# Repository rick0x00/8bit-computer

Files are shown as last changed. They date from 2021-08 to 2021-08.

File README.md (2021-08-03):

# 8bit-computer

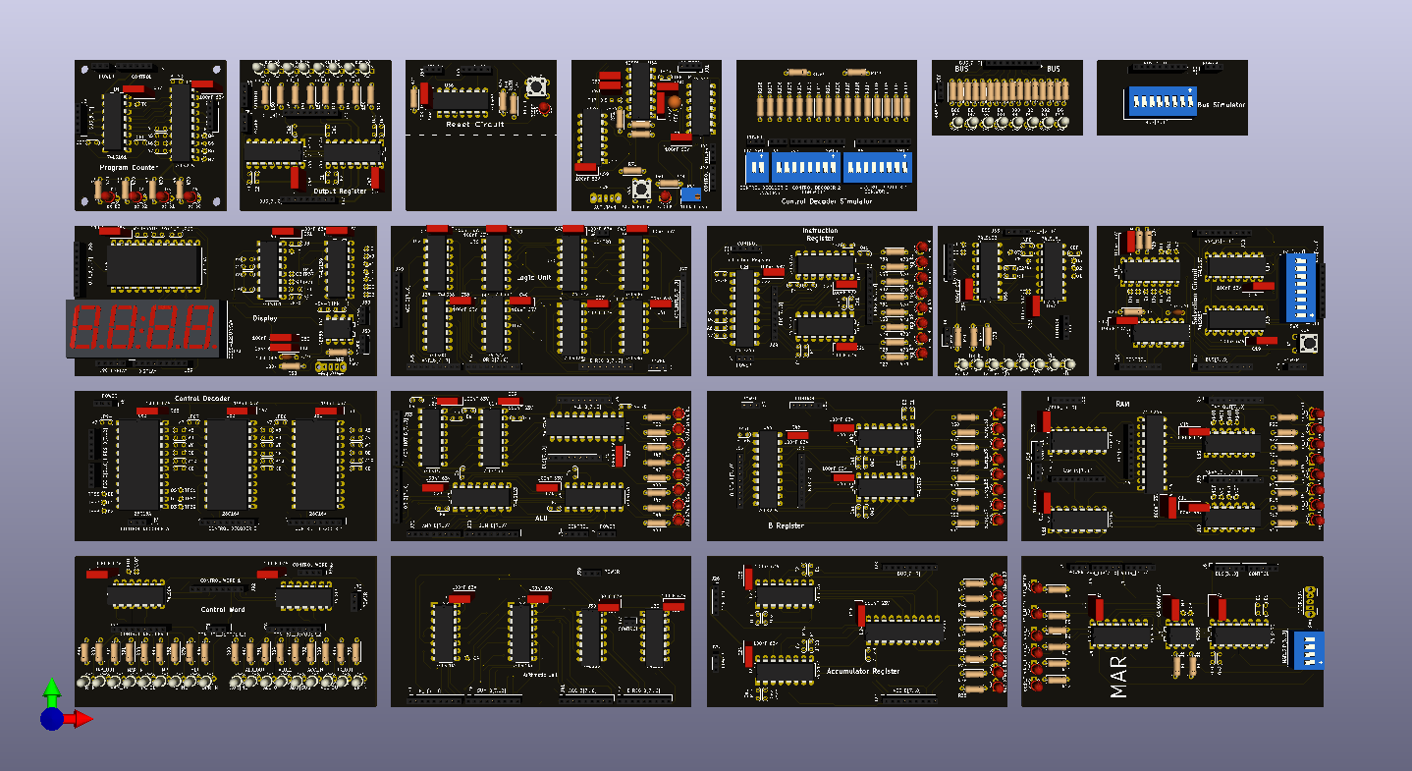
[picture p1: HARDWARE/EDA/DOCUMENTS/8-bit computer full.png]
8bit computer 3D image Kicad


This project intends to develop and distribute following the principles of the [Open Source Initiative(OSI)](https://opensource.org/osd).

The project was based on the model presented by [Wagner Rambo](https://youtube.com/playlist?list=PLZ8dBTV2_5HTB43Mhfz-TyIATkECrp8XY) and also by the project presented by [Ben Eater](https://youtube.com/playlist?list=PLowKtXNTBypGqImE405J2565dvjafglHU), both on youtube!

## Warning
I, the project maintainer ,am a beginner in this Open Source world, Git, GitHub... So I apologize in advance for any problems.

## License
At the present time this project is completely under [Apache 2.0 license](http://www.apache.org/licenses/LICENSE-2.0). All Softwares, All Electronic Designs(Schematics), All Documentation and All 3D Design.

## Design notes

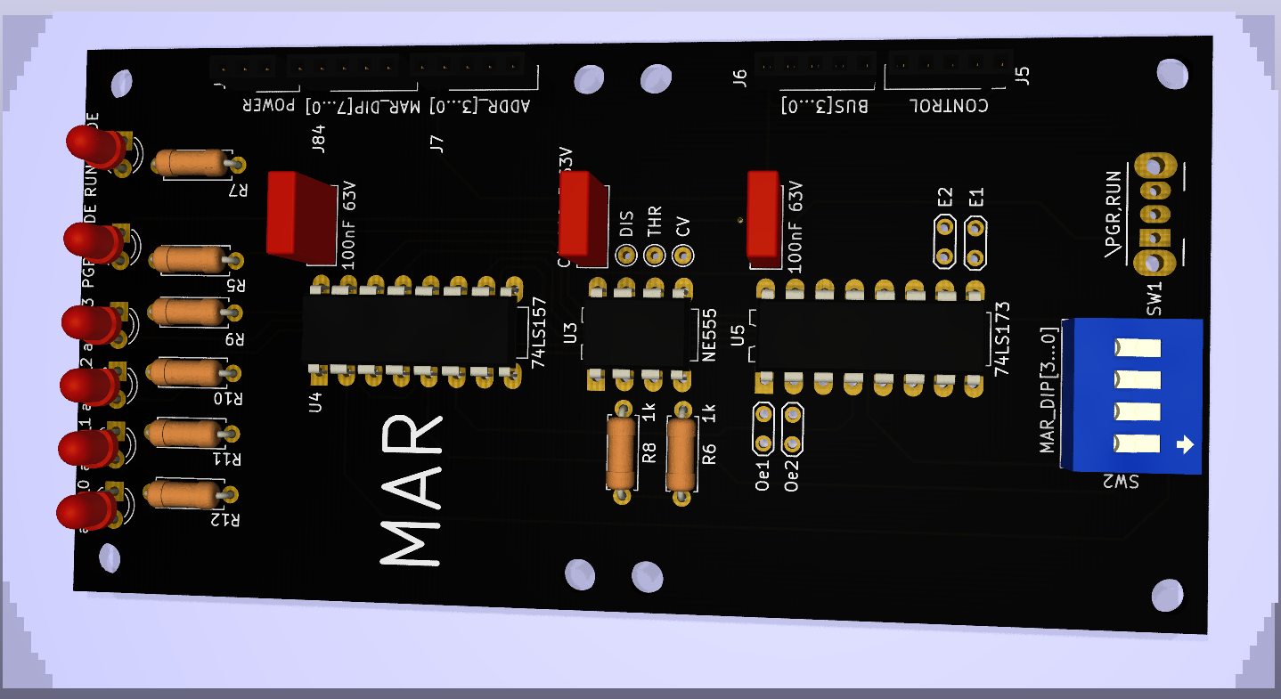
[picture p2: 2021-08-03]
HARDWARE/EDA/DOCUMENTS/MAR.png

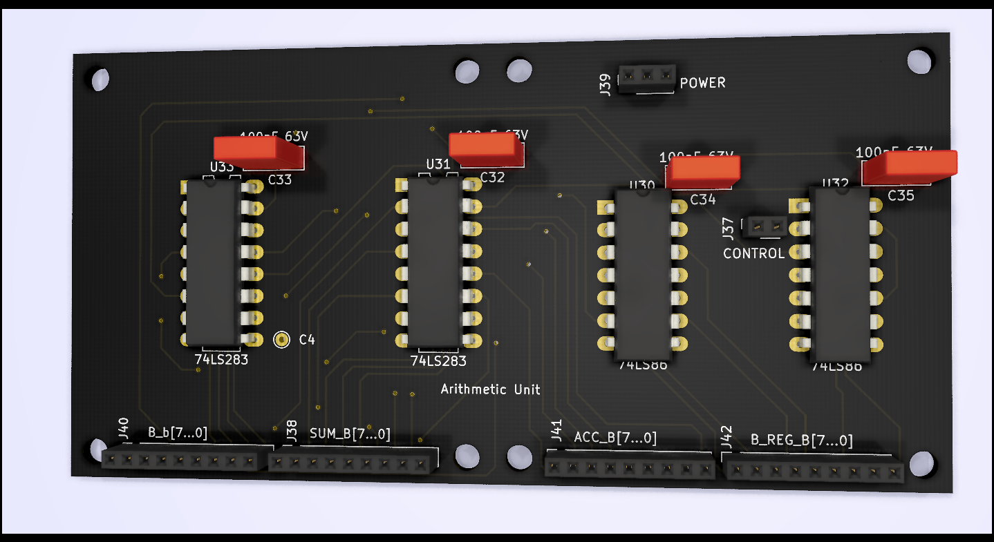
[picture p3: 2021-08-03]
HARDWARE/EDA/DOCUMENTS/Arithmetic Unit.png

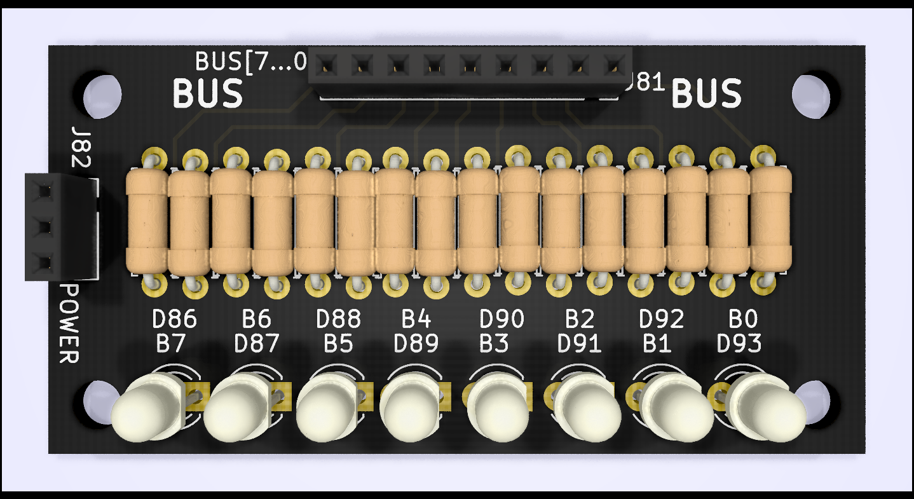
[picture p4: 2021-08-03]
HARDWARE/EDA/DOCUMENTS/BUS.png

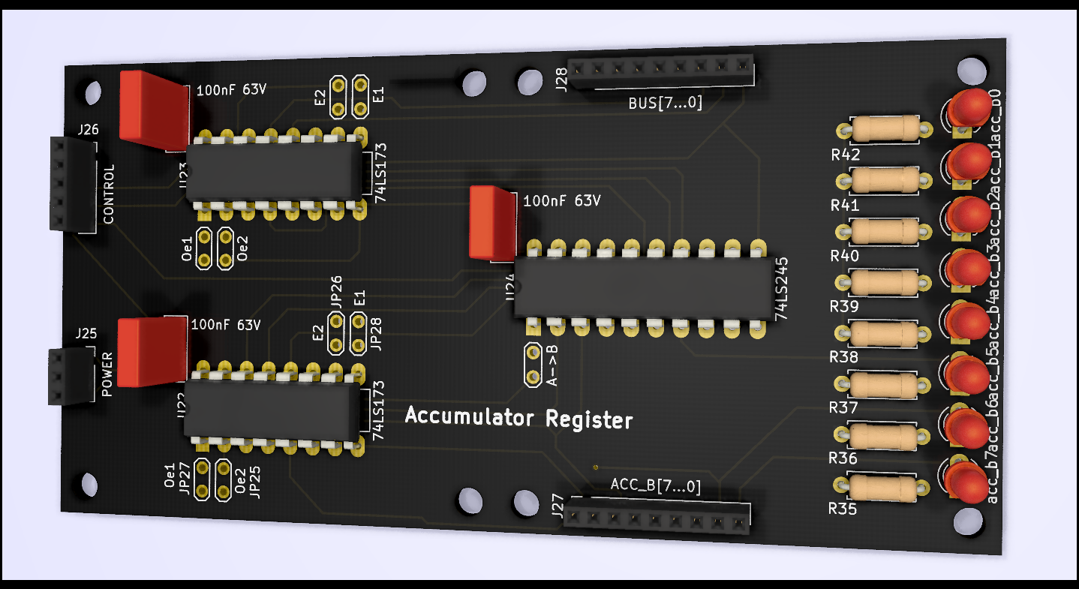
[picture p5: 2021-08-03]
HARDWARE/EDA/DOCUMENTS/Accumulator Register.png

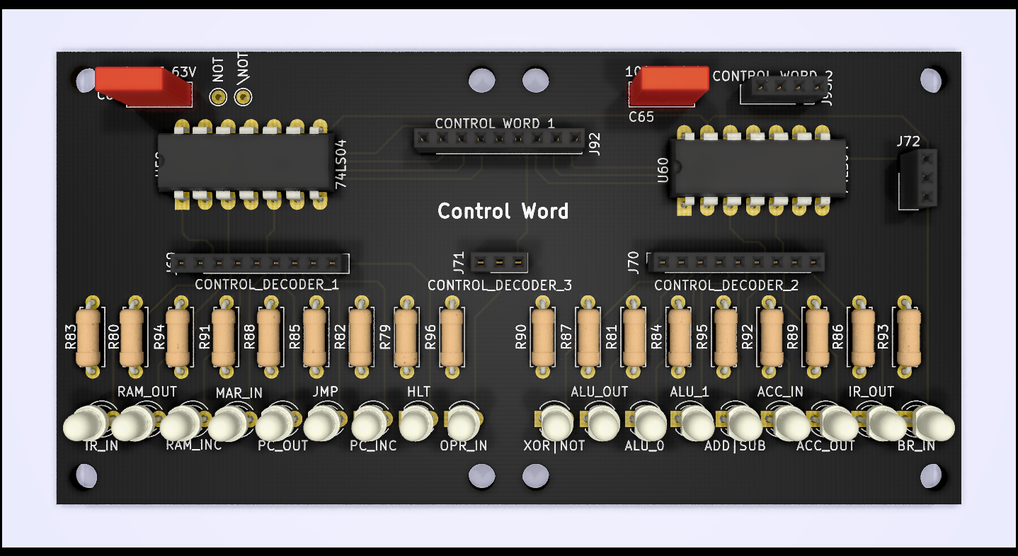
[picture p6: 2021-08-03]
HARDWARE/EDA/DOCUMENTS/Control Word.png

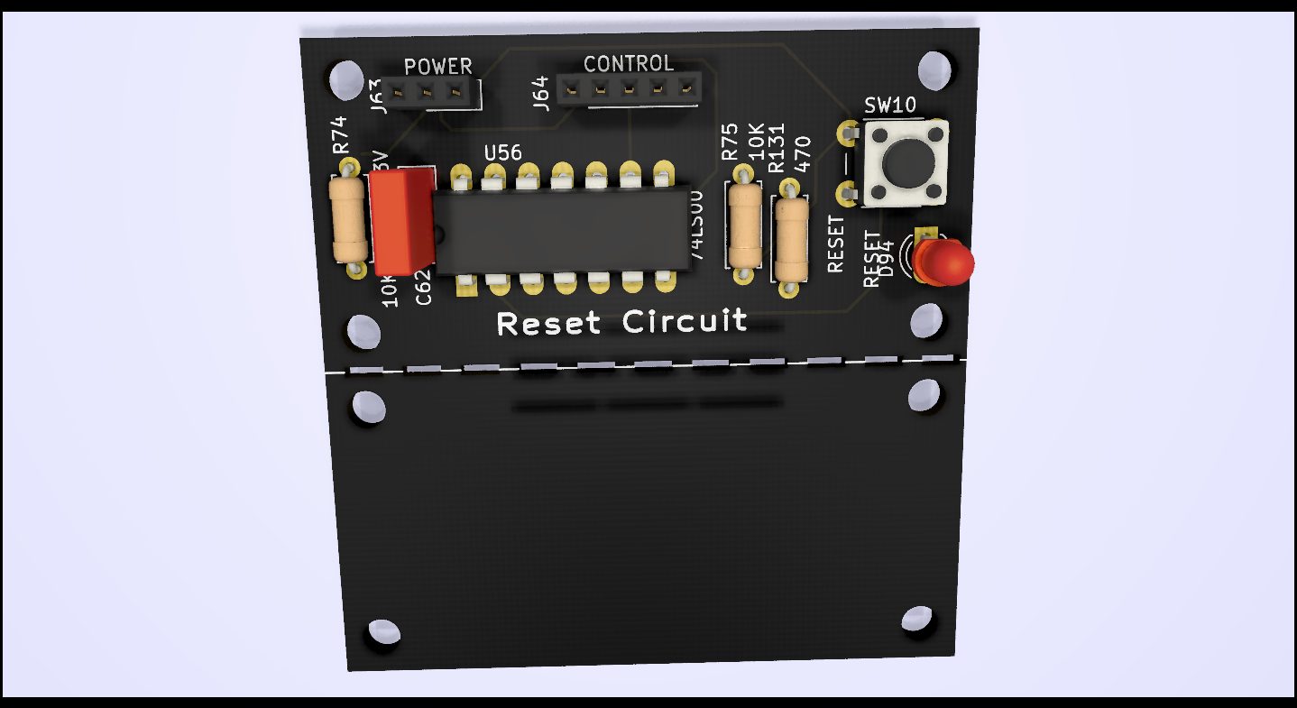
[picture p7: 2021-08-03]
HARDWARE/EDA/DOCUMENTS/Reset Circuit.png

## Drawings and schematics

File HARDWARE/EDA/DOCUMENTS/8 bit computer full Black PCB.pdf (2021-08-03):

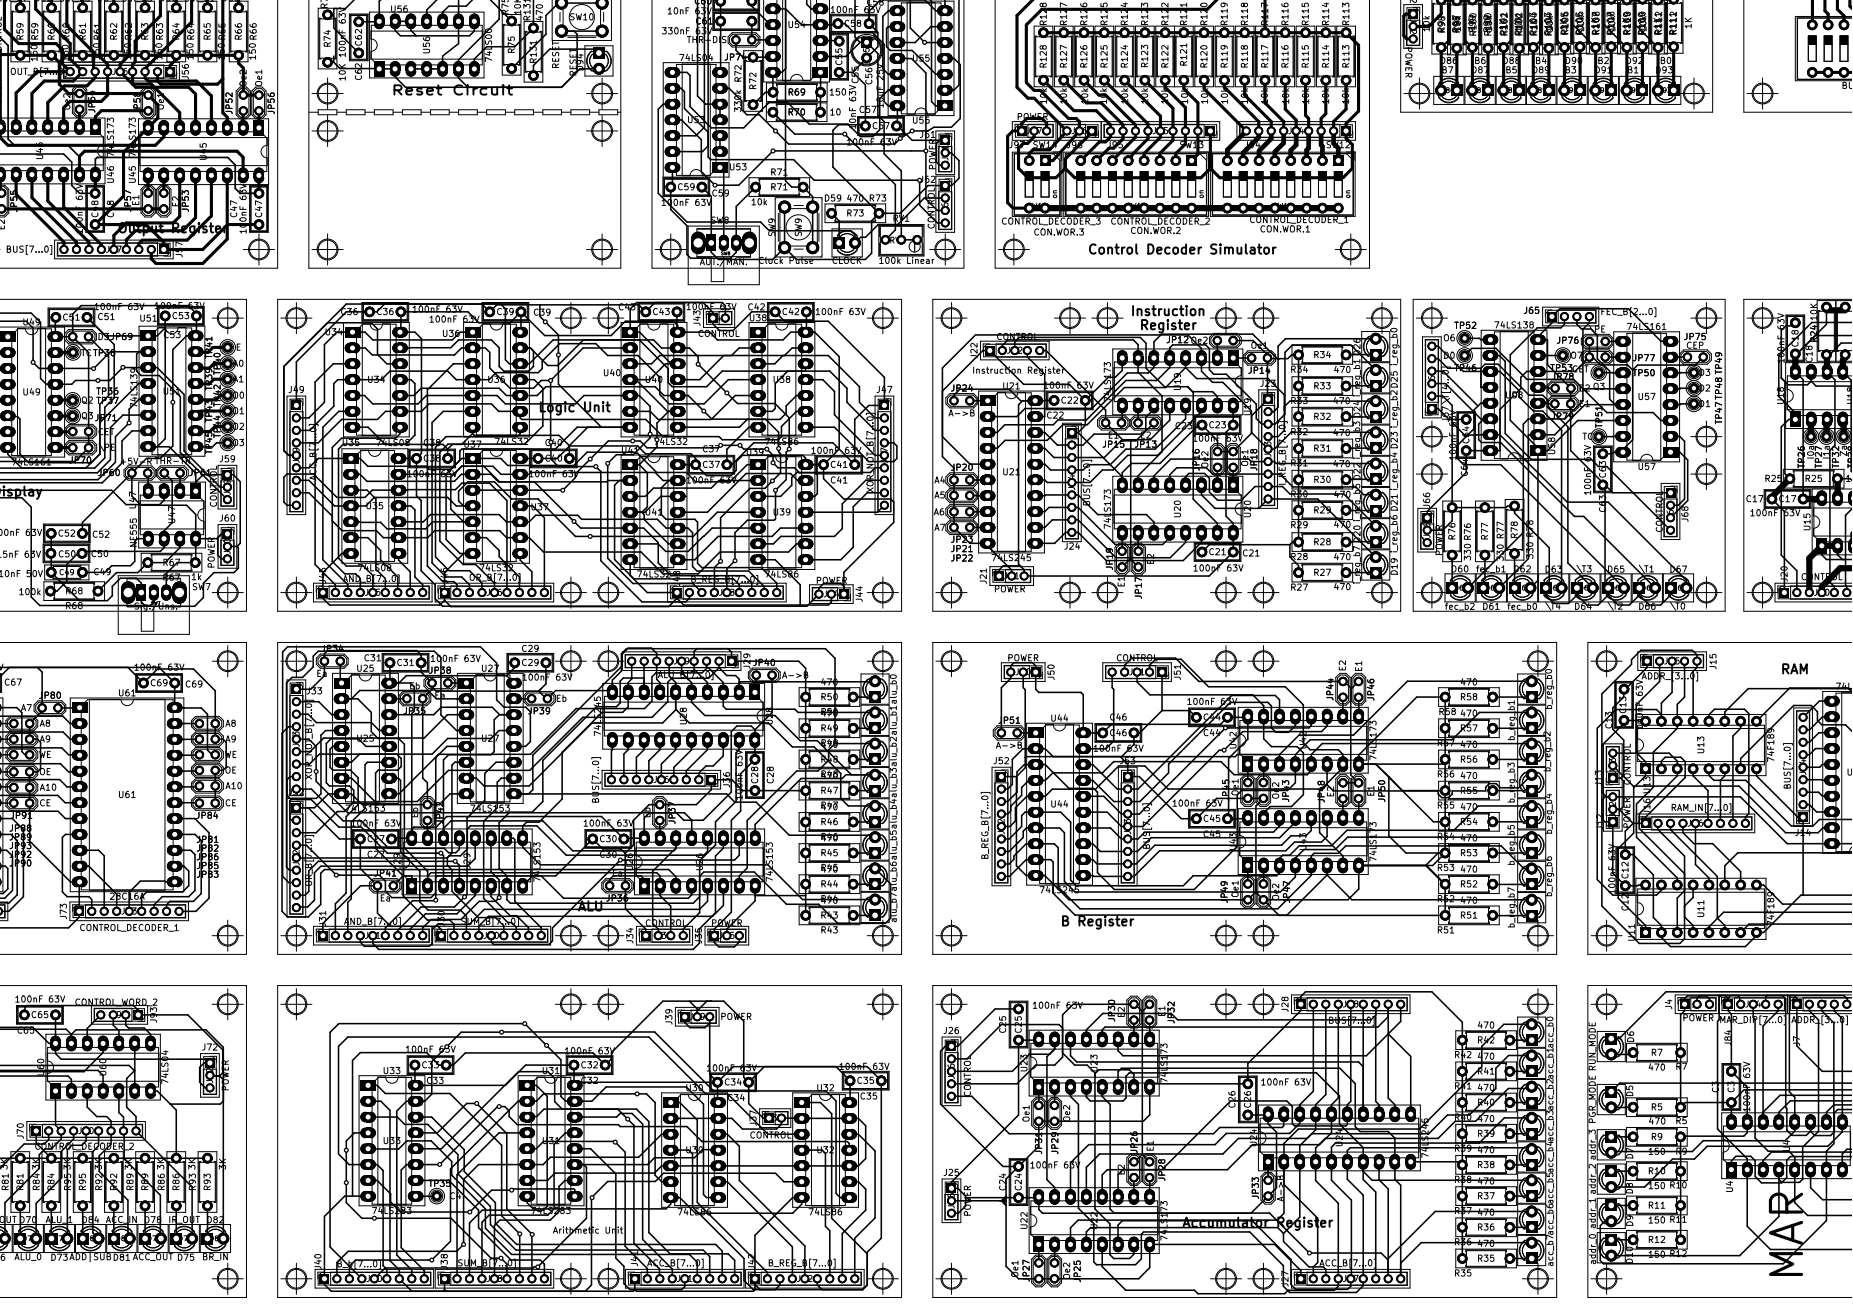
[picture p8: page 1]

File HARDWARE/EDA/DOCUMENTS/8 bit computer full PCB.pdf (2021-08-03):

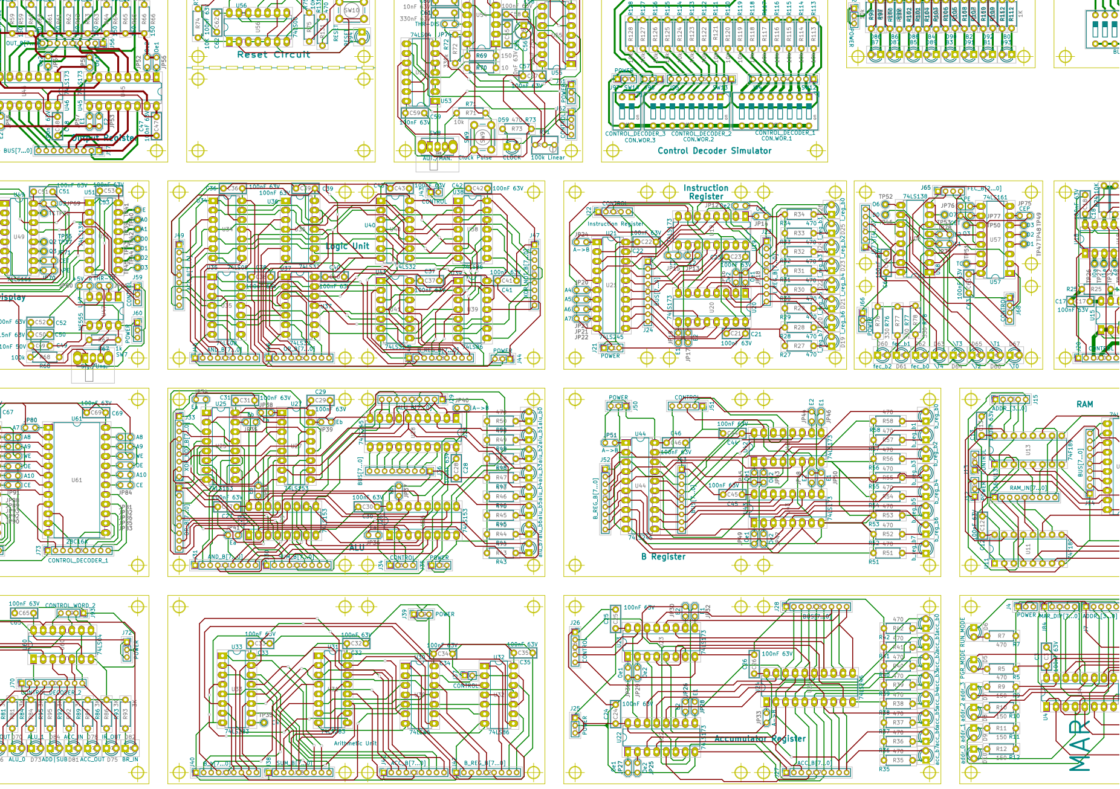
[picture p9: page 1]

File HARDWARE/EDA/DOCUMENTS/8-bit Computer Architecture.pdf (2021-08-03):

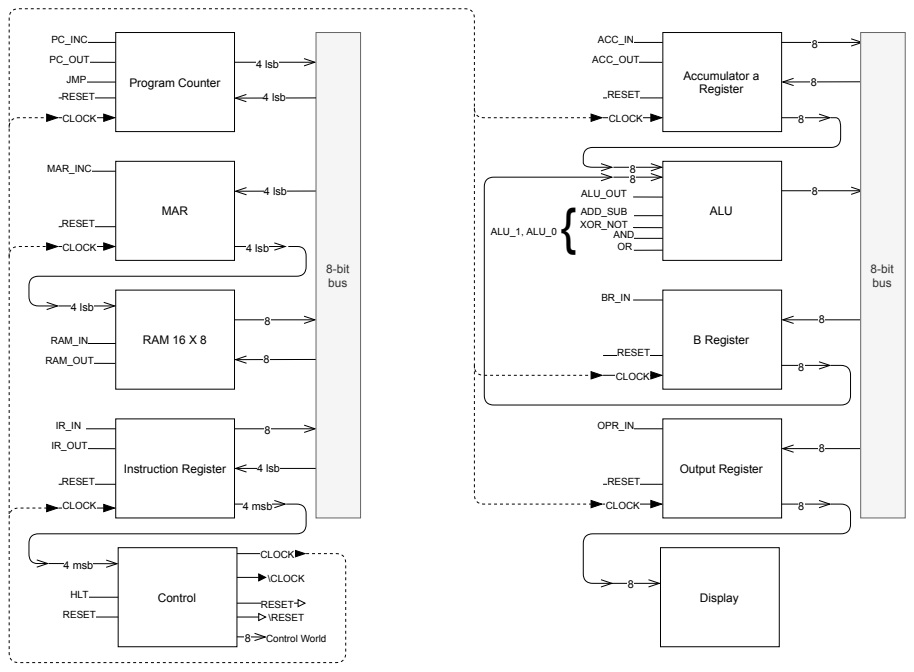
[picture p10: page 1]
Program Counter; CLOCK; PC_INC; JMP; PC_OUT; RESET; MAR; MAR_INC; RAM_IN; RAM 16 X 8; RAM_OUT; Instruction Register; IR_OUT; Control; HLT; \CLOCK; RESET \RESET; Control World; 4 msb; 4 lsb; Accumulator a Register; ACC_IN; ACC_OUT; ALU; XOR_NOT; ALU_OUT; AND; ADD_SUB; B Register; Output Register; OPR_IN; Display; 8-bit bus; ALU_1, ALU_0

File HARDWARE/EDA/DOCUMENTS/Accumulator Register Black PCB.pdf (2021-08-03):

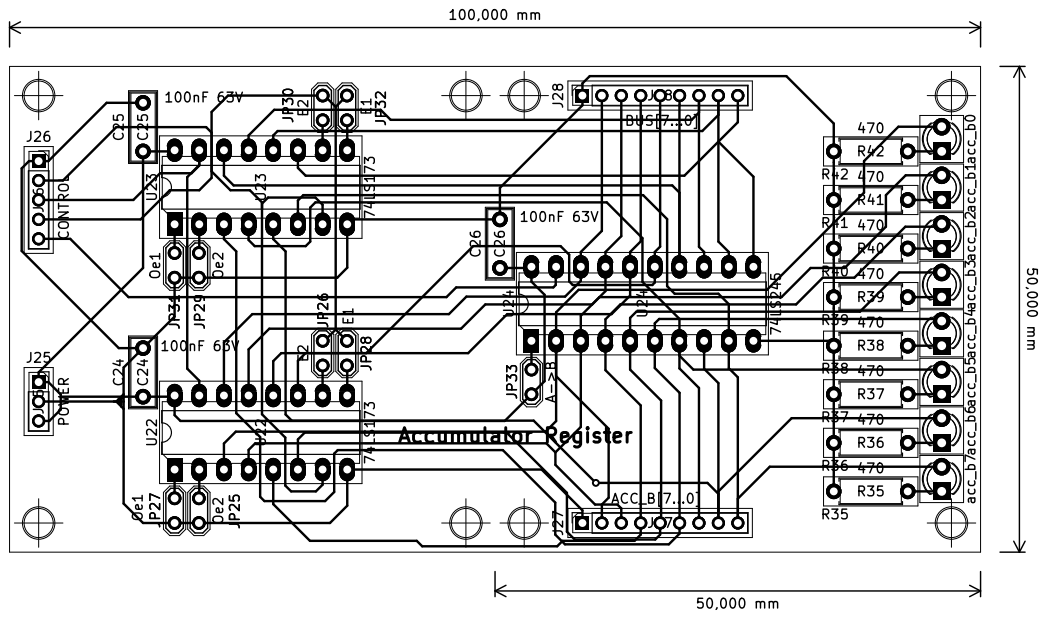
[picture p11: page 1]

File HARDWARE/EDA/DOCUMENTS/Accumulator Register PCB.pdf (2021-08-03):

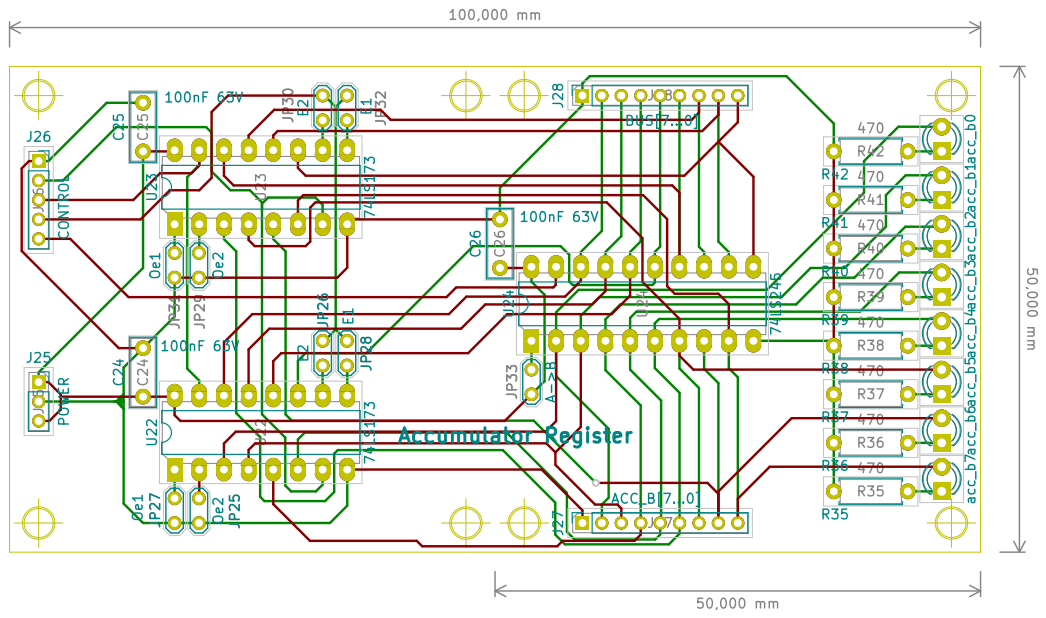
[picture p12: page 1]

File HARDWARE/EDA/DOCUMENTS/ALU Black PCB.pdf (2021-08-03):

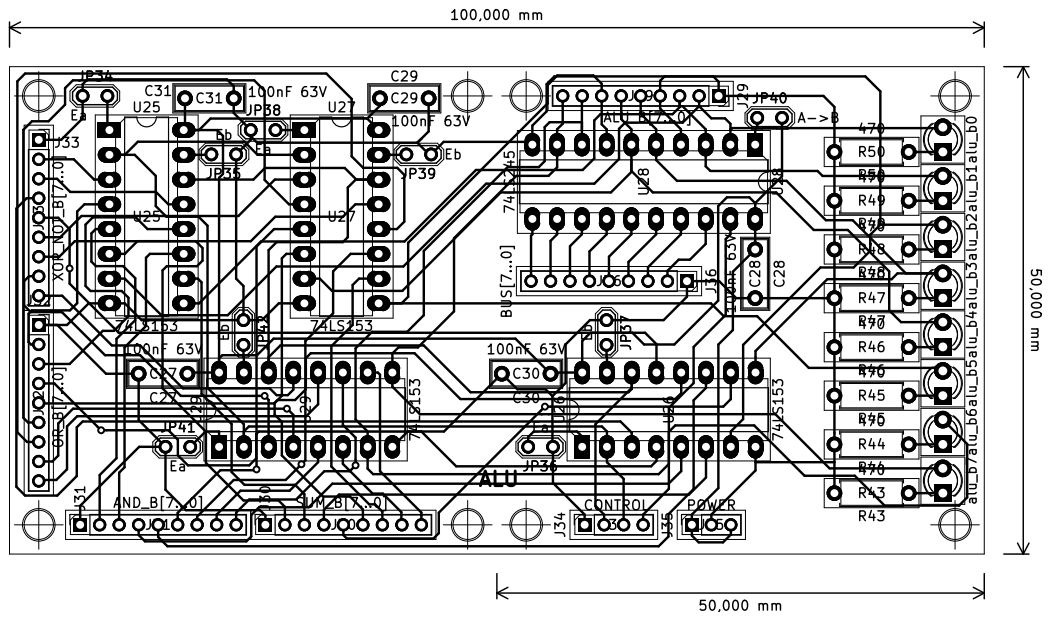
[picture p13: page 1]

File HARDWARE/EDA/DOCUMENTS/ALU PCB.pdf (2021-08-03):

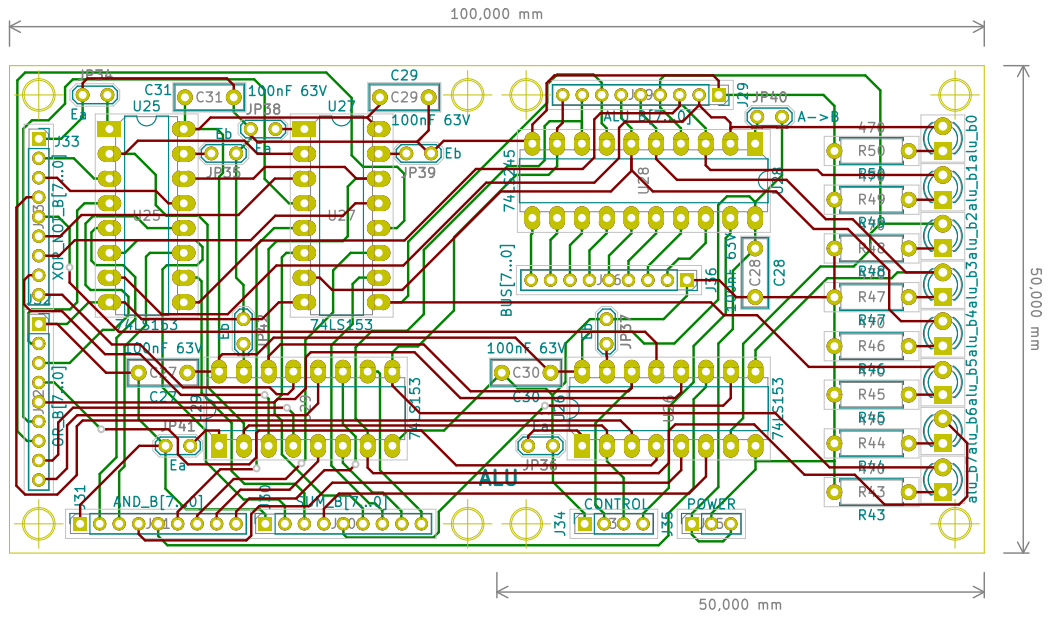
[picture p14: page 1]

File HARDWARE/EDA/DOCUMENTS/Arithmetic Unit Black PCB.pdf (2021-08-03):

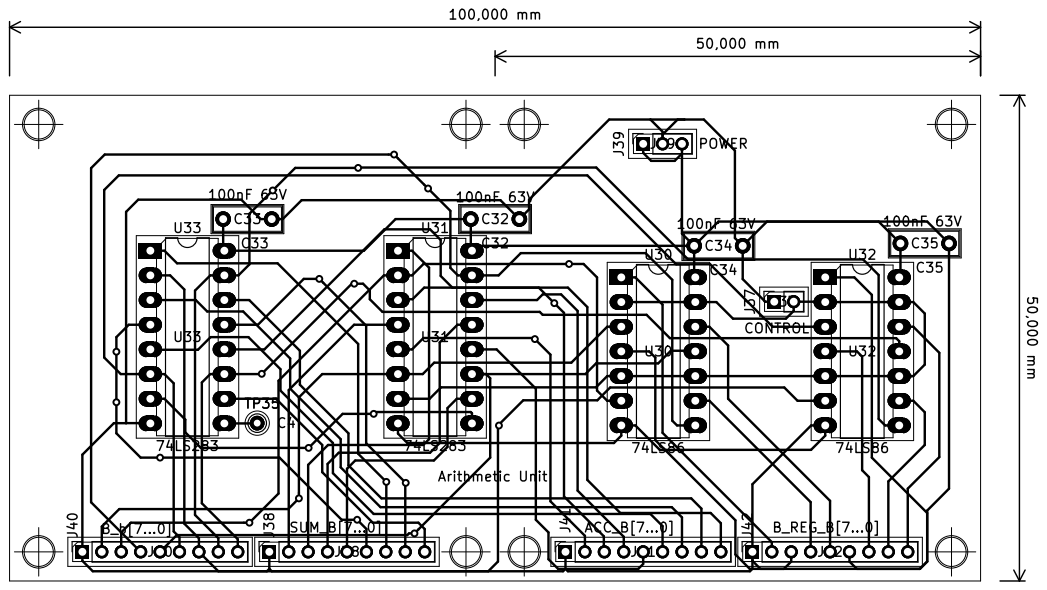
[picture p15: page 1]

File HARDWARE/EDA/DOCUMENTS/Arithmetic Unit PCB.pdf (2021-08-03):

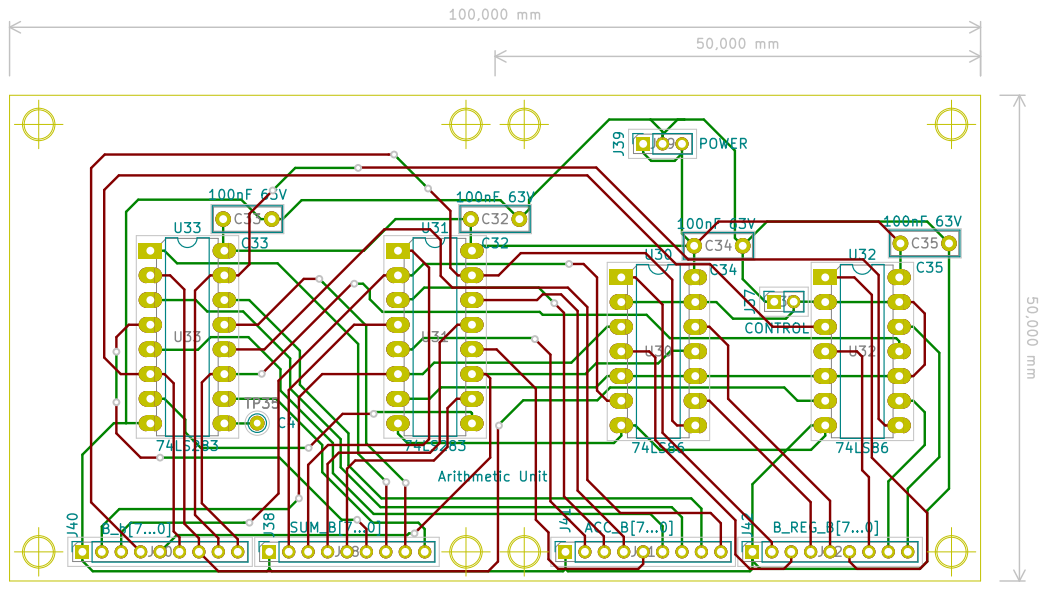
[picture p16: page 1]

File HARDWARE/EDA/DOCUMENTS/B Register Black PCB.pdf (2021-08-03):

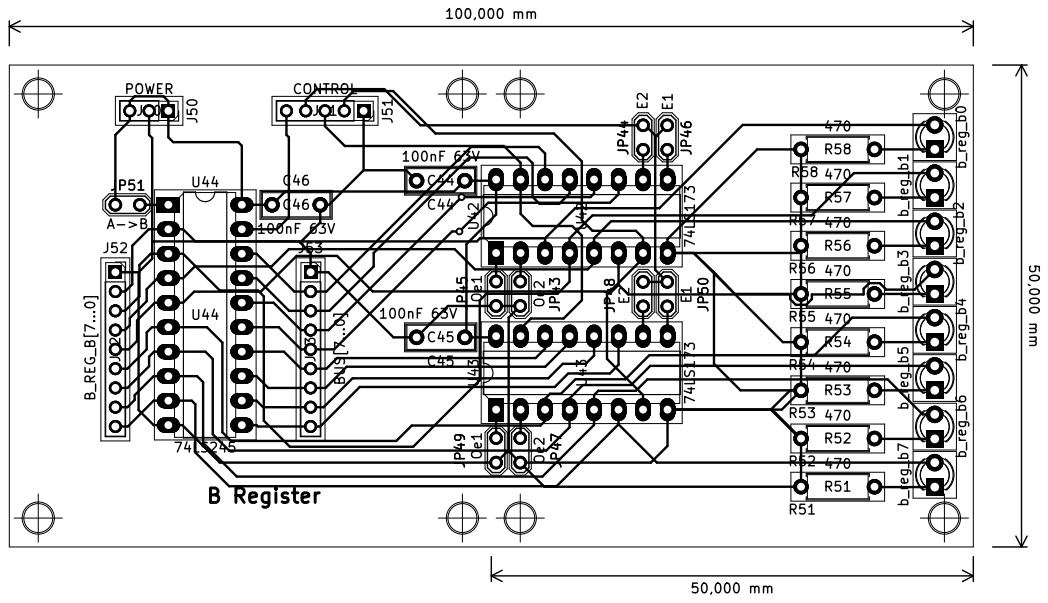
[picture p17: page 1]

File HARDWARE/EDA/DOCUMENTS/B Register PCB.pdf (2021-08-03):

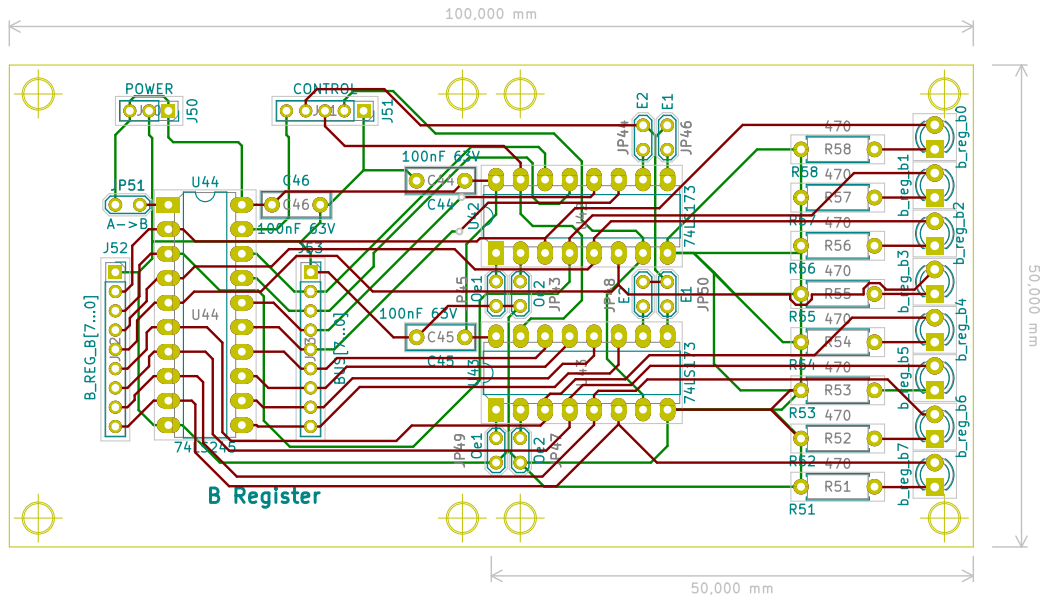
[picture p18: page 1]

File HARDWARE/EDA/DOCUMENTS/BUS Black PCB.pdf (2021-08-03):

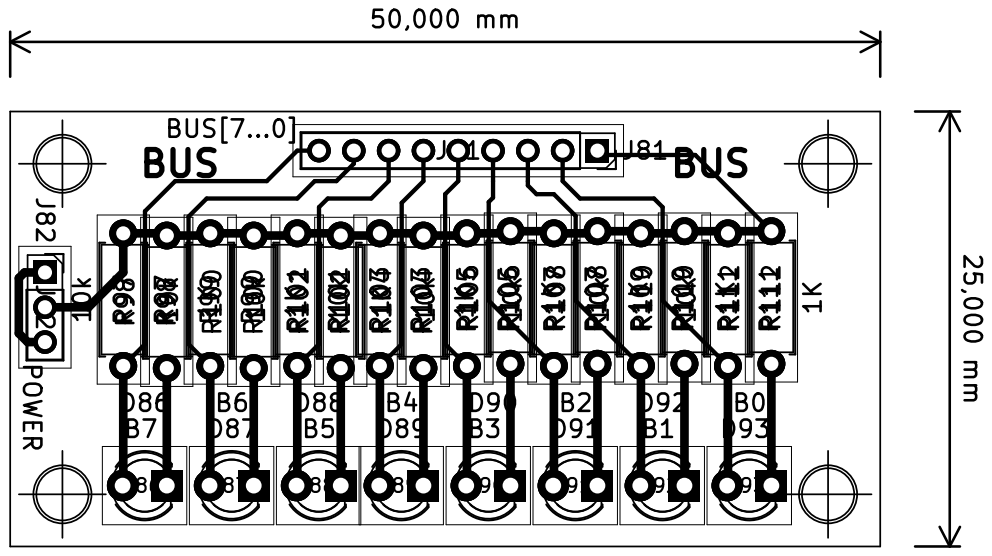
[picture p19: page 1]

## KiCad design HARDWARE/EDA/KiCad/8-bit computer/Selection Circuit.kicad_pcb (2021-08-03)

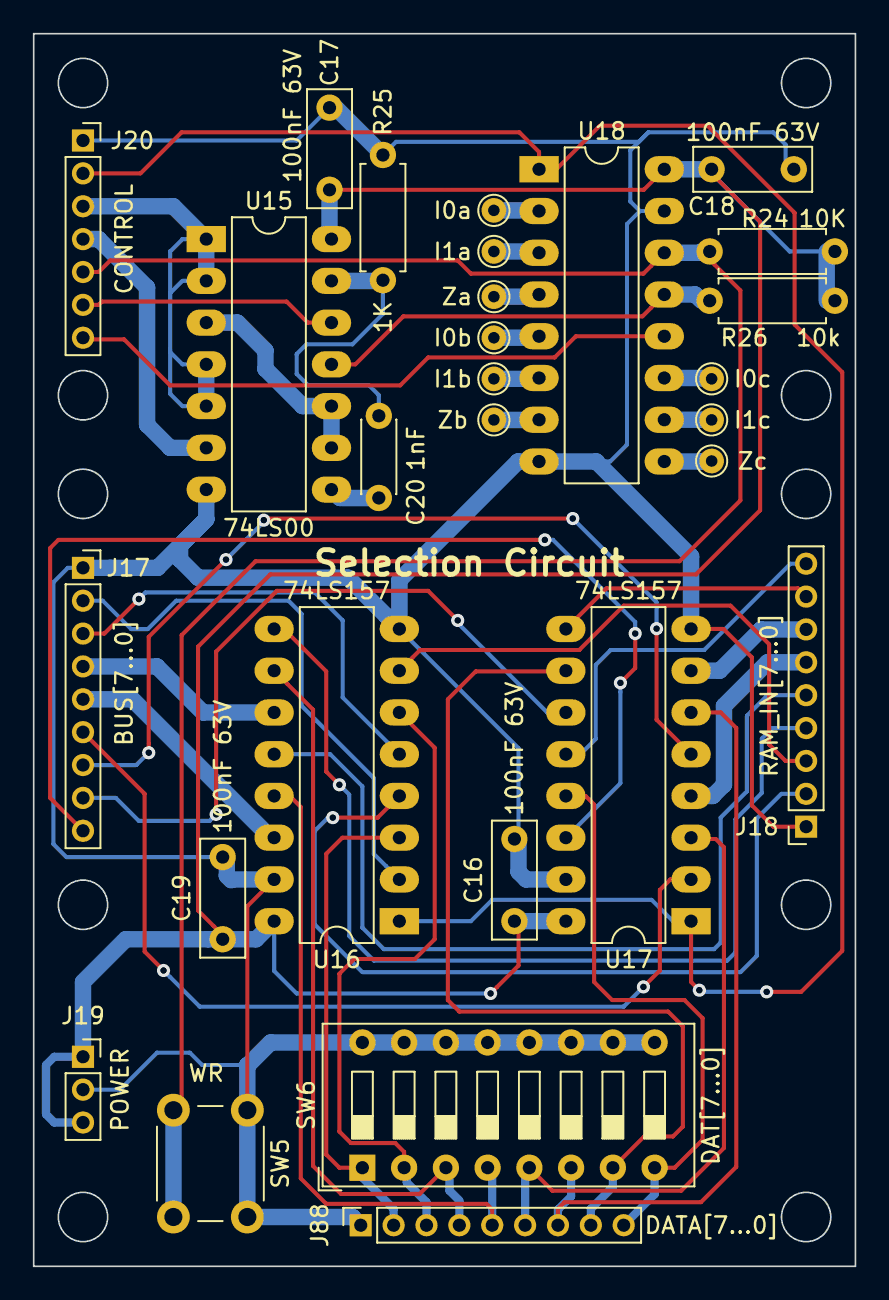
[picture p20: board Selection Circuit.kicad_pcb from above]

Board: 2 copper layers, 50.0 x 75.0 mm, 28 parts (0 on the bottom side), 45 nets.

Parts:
C16, C17, C18, C19: 100nF 63V; C_Rect_L7.0mm_W2.5mm_P5.00mm
C20: 1nF; C_Disc_D4.3mm_W1.9mm_P5.00mm
J17: BUS[7...0]; PinSocket_1x09_P2.00mm_Vertical
J18: RAM_IN[7...0]; PinSocket_1x09_P2.00mm_Vertical
J19: POWER; PinSocket_1x03_P2.00mm_Vertical
J20: CONTROL; PinSocket_1x07_P2.00mm_Vertical
J88: DATA[7...0]; PinSocket_1x09_P2.00mm_Vertical
R24: 10K; R_Axial_DIN0207_L6.3mm_D2.5mm_P7.62mm_Horizontal
R25: 1K; R_Axial_DIN0207_L6.3mm_D2.5mm_P7.62mm_Horizontal
R26: 10k; R_Axial_DIN0207_L6.3mm_D2.5mm_P7.62mm_Horizontal
SW5: WR; SW_PUSH_6mm_H5mm
SW6: DAT[7...0]; SW_DIP_SPSTx08_Slide_9.78x22.5mm_W7.62mm_P2.54mm
TP26: I0a; TestPoint_THTPad_D1.5mm_Drill0.7mm
TP27: I1a; TestPoint_THTPad_D1.5mm_Drill0.7mm
TP28: I0b; TestPoint_THTPad_D1.5mm_Drill0.7mm
TP29: I1b; TestPoint_THTPad_D1.5mm_Drill0.7mm
TP30: I0c; TestPoint_THTPad_D1.5mm_Drill0.7mm
TP31: I1c; TestPoint_THTPad_D1.5mm_Drill0.7mm
TP32: Za; TestPoint_THTPad_D1.5mm_Drill0.7mm
TP33: Zb; TestPoint_THTPad_D1.5mm_Drill0.7mm
TP34: Zc; TestPoint_THTPad_D1.5mm_Drill0.7mm
U15: 74LS00; DIP-14_W7.62mm_LongPads
U16, U17, U18: 74LS157; DIP-16_W7.62mm_LongPads

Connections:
+5V: C16.1, C17.1, C18.1, C19.1, J19.1, J19.3, R24.1, R26.1, U15.14, U16.16, U17.16, U18.16
/dat0: J88.2, SW6.1, U16.3
/dat1: J88.3, SW6.2, U16.6
/dat2: J88.4, SW6.3, U16.10
/dat3: J88.5, SW6.4, U16.13
/dat4: J88.6, SW6.5, U17.3
/dat5: J88.7, SW6.6, U17.6
/dat6: J88.8, SW6.7, U17.10
/dat7: J88.9, SW6.8, U17.13
CLOCK: J20.3, U15.1, U15.2, U15.4, U15.5
GND: C16.2, C17.2, C18.2, C19.2, J17.1, J18.1, J19.2, J20.1, J88.1, R25.2, SW5.1, SW6.9, SW6.10, SW6.11, SW6.12, SW6.13, SW6.14, SW6.15, SW6.16, U15.7, U16.8, U16.15, U17.8, U17.15, U18.8, U18.15
unnamed: C20.1, R25.1, U15.13
unnamed: C20.2, U15.8
unnamed: R26.2, U15.11, U18.13
unnamed: TP26.1, U18.2
unnamed: TP27.1, U18.3
unnamed: TP28.1, U18.5
unnamed: TP29.1, U18.6
unnamed: TP30.1, U18.11
unnamed: TP31.1, U18.10
unnamed: TP32.1, U18.4
unnamed: TP33.1, U18.7
unnamed: TP34.1, U18.9
unnamed: U15.3, U15.9, U15.10
RAM_IN: J20.6, U15.12
WR_BUTTON: J20.5, R24.2, SW5.2, U18.14
\CLOCK: J20.4, U15.6
\Program,Run: J20.2, U16.1, U17.1, U18.1
\WE: J20.7, U18.12
bus0: J17.2, U16.2
bus1: J17.3, U16.5
bus2: J17.4, U16.11
bus3: J17.5, U16.14
bus4: J17.6, U17.2
bus5: J17.7, U17.5
bus6: J17.8, U17.11
bus7: J17.9, U17.14
ram_in0: J18.2, U16.4
ram_in1: J18.3, U16.7
ram_in2: J18.4, U16.9
ram_in3: J18.5, U16.12
ram_in4: J18.6, U17.4
ram_in5: J18.7, U17.7
ram_in6: J18.8, U17.9
ram_in7: J18.9, U17.12

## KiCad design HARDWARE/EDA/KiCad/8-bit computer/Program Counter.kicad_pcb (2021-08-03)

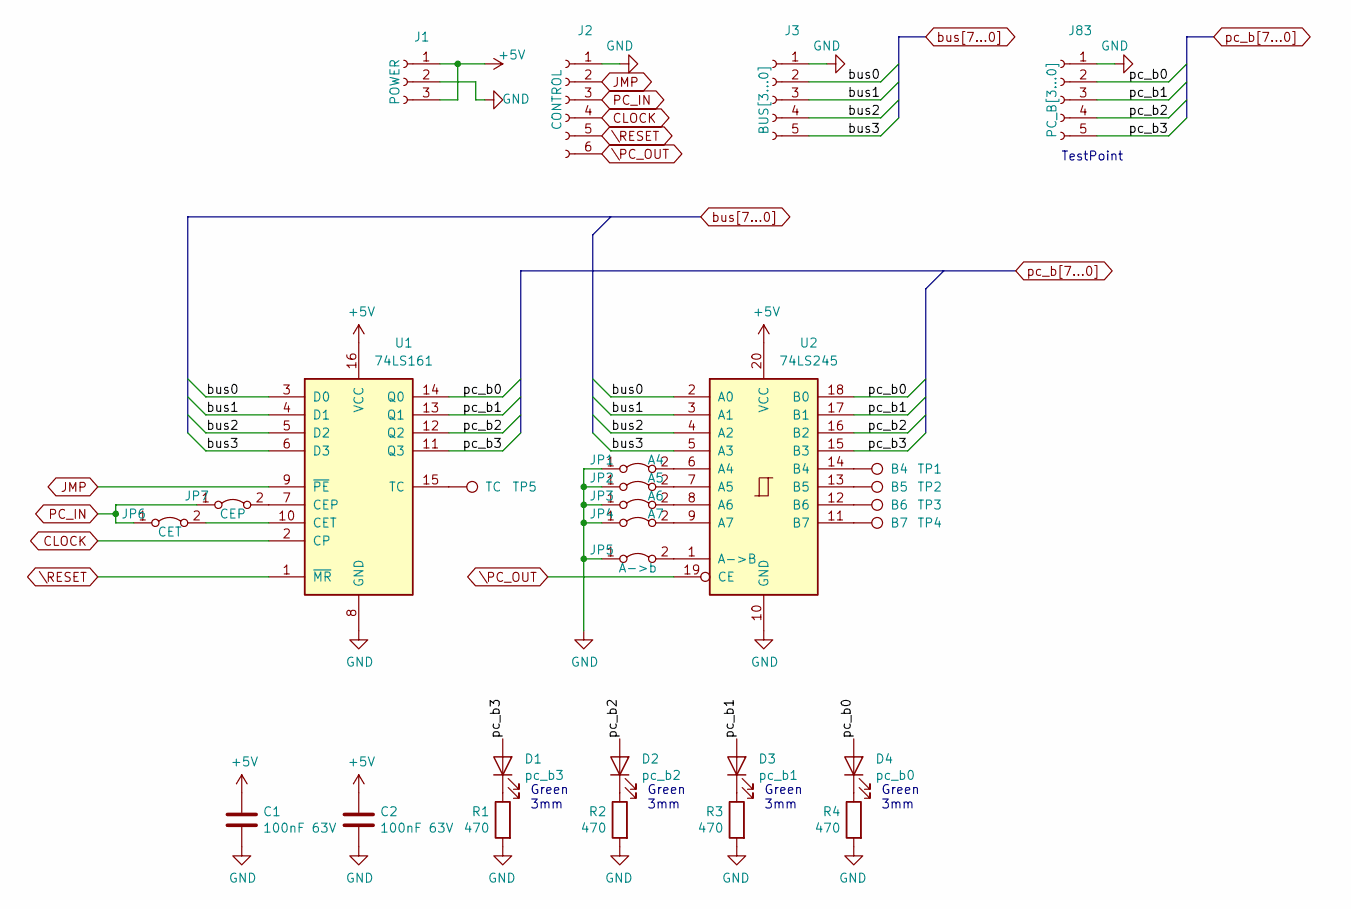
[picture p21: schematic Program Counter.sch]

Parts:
C1, C2: 100nF 63V; C_Rect_L7.0mm_W2.5mm_P5.00mm
D1: pc_b3; LED_D3.0mm
D2: pc_b2; LED_D3.0mm
D3: pc_b1; LED_D3.0mm
D4: pc_b0; LED_D3.0mm
J1: POWER; PinSocket_1x03_P2.00mm_Vertical
J2: CONTROL; PinSocket_1x06_P2.00mm_Vertical
J3: BUS[3...0]; PinSocket_1x05_P2.00mm_Vertical
J83: PC_B[3...0]; PinSocket_1x05_P2.00mm_Vertical
JP1: A4; TestPoint_2Pads_Pitch2.54mm_Drill0.8mm
JP2: A5; TestPoint_2Pads_Pitch2.54mm_Drill0.8mm
JP3: A6; TestPoint_2Pads_Pitch2.54mm_Drill0.8mm
JP4: A7; TestPoint_2Pads_Pitch2.54mm_Drill0.8mm
JP5: A->b; TestPoint_2Pads_Pitch2.54mm_Drill0.8mm
JP6: CET; TestPoint_2Pads_Pitch2.54mm_Drill0.8mm
JP7: CEP; TestPoint_2Pads_Pitch2.54mm_Drill0.8mm
R1, R2, R3, R4: 470; R_Axial_DIN0207_L6.3mm_D2.5mm_P7.62mm_Horizontal
TP1: B4; TestPoint_THTPad_D1.5mm_Drill0.7mm
TP2: B5; TestPoint_THTPad_D1.5mm_Drill0.7mm
TP3: B6; TestPoint_THTPad_D1.5mm_Drill0.7mm
TP4: B7; TestPoint_THTPad_D1.5mm_Drill0.7mm
TP5: TC; TestPoint_THTPad_D1.5mm_Drill0.7mm
U1: 74LS161; DIP-16_W7.62mm_LongPads
U2: 74LS245; DIP-20_W7.62mm_LongPads

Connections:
+5V: C1.1, C2.1, J1.1, J1.3, U1.16 (VCC), U2.20 (VCC)
CLOCK: J2.4, U1.2 (CP)
GND: C1.2, C2.2, J1.2, J2.1, J3.1, J83.1, JP1.1 (A), JP2.1 (A), JP3.1 (A), JP4.1 (A), JP5.1 (A), R1.2, R2.2, R3.2, R4.2, U1.8 (GND), U2.10 (GND)
JMP: J2.2, U1.9 (~PE)
unnamed: D1.1 (K), R1.1
unnamed: D2.1 (K), R2.1
unnamed: D3.1 (K), R3.1
unnamed: D4.1 (K), R4.1
unnamed: JP1.2 (B), U2.6 (A4)
unnamed: JP2.2 (B), U2.7 (A5)
unnamed: JP3.2 (B), U2.8 (A6)
unnamed: JP4.2 (B), U2.9 (A7)
unnamed: JP5.2 (B), U2.1 (A->B)
unnamed: JP6.2 (B), U1.10 (CET)
unnamed: JP7.2 (B), U1.7 (CEP)
unnamed: TP1.1, U2.14 (B4)
unnamed: TP2.1, U2.13 (B5)
unnamed: TP3.1, U2.12 (B6)
unnamed: TP4.1, U2.11 (B7)
unnamed: TP5.1, U1.15 (TC)
PC_IN: J2.3, JP6.1 (A), JP7.1 (A)
\PC_OUT: J2.6, U2.19 (CE)
\RESET: J2.5, U1.1 (~MR)
bus0: J3.2, U1.3 (D0), U2.2 (A0)
bus1: J3.3, U1.4 (D1), U2.3 (A1)
bus2: J3.4, U1.5 (D2), U2.4 (A2)
bus3: J3.5, U1.6 (D3), U2.5 (A3)
pc_b0: D4.2 (A), J83.2, U1.14 (Q0), U2.18 (B0)
pc_b1: D3.2 (A), J83.3, U1.13 (Q1), U2.17 (B1)
pc_b2: D2.2 (A), J83.4, U1.12 (Q2), U2.16 (B2)
pc_b3: D1.2 (A), J83.5, U1.11 (Q3), U2.15 (B3)

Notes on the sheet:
Green 3mm
TestPoint

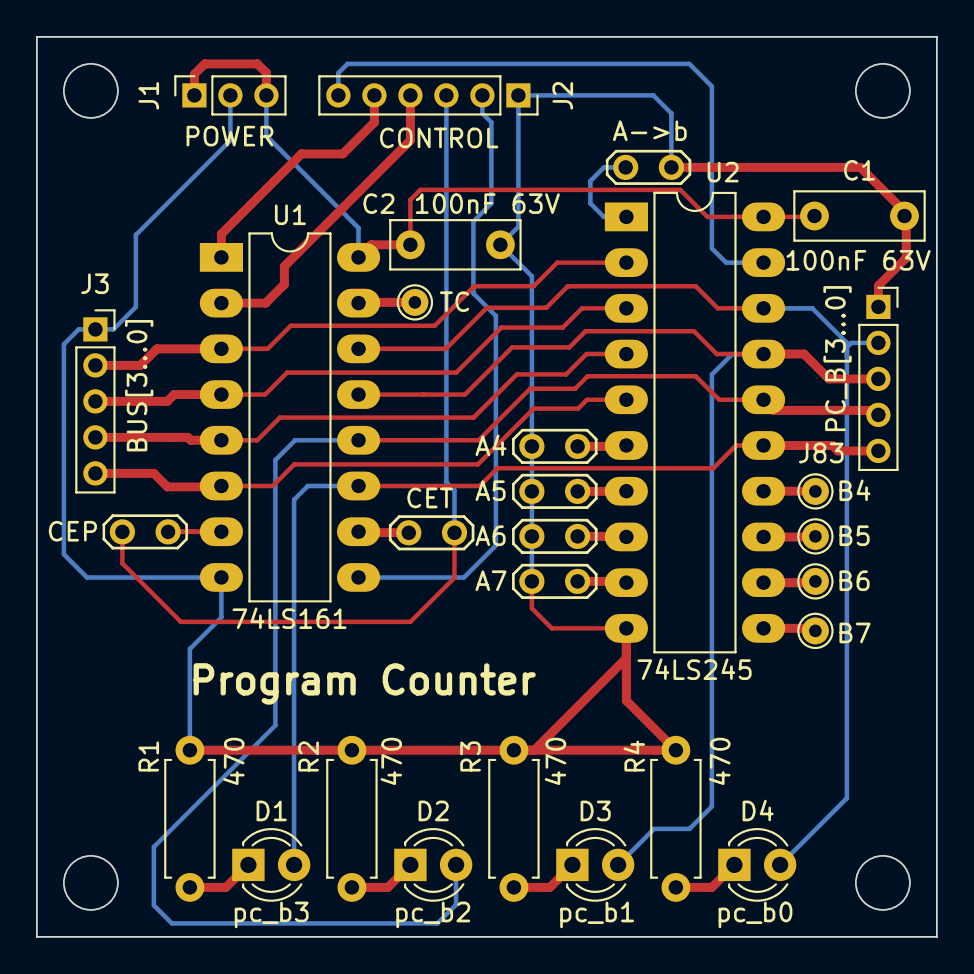
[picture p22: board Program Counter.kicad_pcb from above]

Board: 2 copper layers, 50.0 x 50.0 mm, 28 parts (0 on the bottom side), 31 nets.

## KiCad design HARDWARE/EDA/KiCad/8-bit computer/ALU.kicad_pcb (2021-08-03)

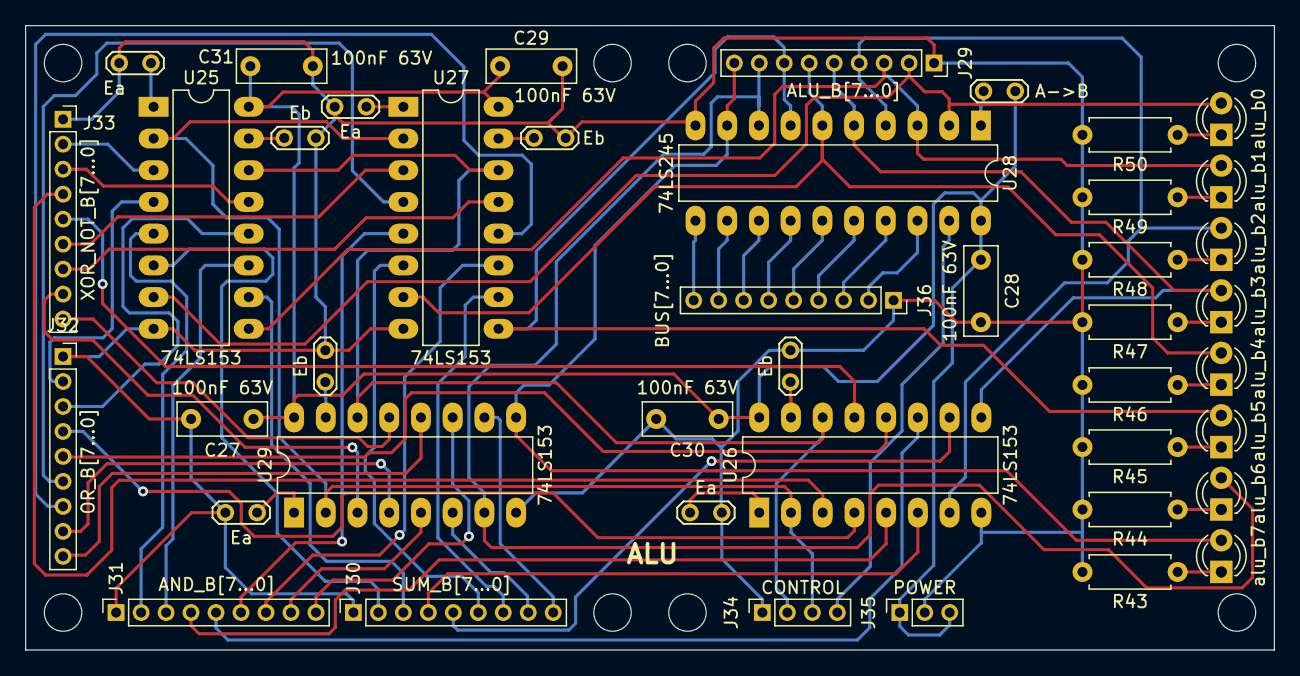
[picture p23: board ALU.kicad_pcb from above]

Board: 2 copper layers, 100.0 x 50.0 mm, 43 parts (0 on the bottom side), 70 nets.

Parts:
C27, C28, C29, C30, C31: 100nF 63V; C_Rect_L7.0mm_W2.5mm_P5.00mm
D35: alu_b7; LED_D3.0mm
D36: alu_b6; LED_D3.0mm
D37: alu_b5; LED_D3.0mm
D38: alu_b4; LED_D3.0mm
D39: alu_b3; LED_D3.0mm
D40: alu_b2; LED_D3.0mm
D41: alu_b1; LED_D3.0mm
D42: alu_b0; LED_D3.0mm
J29: ALU_B[7...0]; PinSocket_1x09_P2.00mm_Vertical
J30: SUM_B[7...0]; PinSocket_1x09_P2.00mm_Vertical
J31: AND_B[7...0]; PinSocket_1x09_P2.00mm_Vertical
J32: OR_B[7...0]; PinSocket_1x09_P2.00mm_Vertical
J33: XOR_NOT_B[7...0]; PinSocket_1x09_P2.00mm_Vertical
J34: CONTROL; PinSocket_1x04_P2.00mm_Vertical
J35: POWER; PinSocket_1x03_P2.00mm_Vertical
J36: BUS[7...0]; PinSocket_1x09_P2.00mm_Vertical
JP34, JP36, JP38, JP41: Ea; TestPoint_2Pads_Pitch2.54mm_Drill0.8mm
JP35, JP37, JP39, JP42: Eb; TestPoint_2Pads_Pitch2.54mm_Drill0.8mm
JP40: A->B; TestPoint_2Pads_Pitch2.54mm_Drill0.8mm
R43, R44, R45, R46, R47, R48, R49, R50: 470; R_Axial_DIN0207_L6.3mm_D2.5mm_P7.62mm_Horizontal
U25, U26, U27, U29: 74LS153; DIP-16_W7.62mm_LongPads
U28: 74LS245; DIP-20_W7.62mm_LongPads

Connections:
+5V: C27.1, C28.1, C29.1, C30.1, C31.1, J35.1, J35.3, JP40.1, U25.16, U26.16, U27.16, U28.20, U29.16
ALU_0: J34.2, U25.14, U26.14, U27.14, U29.14
ALU_1: J34.3, U25.2, U26.2, U27.2, U29.2
GND: C27.2, C28.2, C29.2, C30.2, C31.2, J29.1, J30.1, J31.1, J32.1, J33.1, J34.1, J35.2, J36.1, JP34.1, JP35.1, JP36.1, JP37.1, JP38.1, JP39.1, JP41.1, JP42.1, R43.2, R44.2, R45.2, R46.2, R47.2, R48.2, R49.2, R50.2, U25.8, U26.8, U27.8, U28.10, U29.8
unnamed: D35.1, R43.1
unnamed: D36.1, R44.1
unnamed: D37.1, R45.1
unnamed: D38.1, R46.1
unnamed: D39.1, R47.1
unnamed: D40.1, R48.1
unnamed: D41.1, R49.1
unnamed: D42.1, R50.1
unnamed: JP34.2, U25.1
unnamed: JP35.2, U25.15
unnamed: JP36.2, U26.1
unnamed: JP37.2, U26.15
unnamed: JP38.2, U27.1
unnamed: JP39.2, U27.15
unnamed: JP40.2, U28.1
unnamed: JP41.2, U29.1
unnamed: JP42.2, U29.15
\ALU_OUT: J34.4, U28.19
alu_b0: D42.2, J29.2, U25.7, U28.2
alu_b1: D41.2, J29.3, U25.9, U28.3
alu_b2: D40.2, J29.4, U26.7, U28.4
alu_b3: D39.2, J29.5, U26.9, U28.5
alu_b4: D38.2, J29.6, U27.7, U28.6
alu_b5: D37.2, J29.7, U27.9, U28.7
alu_b6: D36.2, J29.8, U28.8, U29.7
alu_b7: D35.2, J29.9, U28.9, U29.9
and_b0: J31.2, U25.5
and_b1: J31.3, U25.11
and_b2: J31.4, U26.5
and_b3: J31.5, U26.11
and_b4: J31.6, U27.5
and_b5: J31.7, U27.11
and_b6: J31.8, U29.5
and_b7: J31.9, U29.11
bus0: J36.2, U28.18
bus1: J36.3, U28.17
bus2: J36.4, U28.16
bus3: J36.5, U28.15
bus4: J36.6, U28.14
bus5: J36.7, U28.13
bus6: J36.8, U28.12
bus7: J36.9, U28.11
or_b0: J32.2, U25.4
or_b1: J32.3, U25.12
or_b2: J32.4, U26.4
or_b3: J32.5, U26.12
or_b4: J32.6, U27.4
or_b5: J32.7, U27.12
or_b6: J32.8, U29.4
or_b7: J32.9, U29.12
sum_b0: J30.2, U25.6
sum_b1: J30.3, U25.10
sum_b2: J30.4, U26.6
sum_b3: J30.5, U26.10
sum_b4: J30.6, U27.6
sum_b5: J30.7, U27.10
sum_b6: J30.8, U29.6
sum_b7: J30.9, U29.10
xor_not_b0: J33.2, U25.3
xor_not_b1: J33.3, U25.13
xor_not_b2: J33.4, U26.3
xor_not_b3: J33.5, U26.13
xor_not_b4: J33.6, U27.3
xor_not_b5: J33.7, U27.13
xor_not_b6: J33.8, U29.3
xor_not_b7: J33.9, U29.13

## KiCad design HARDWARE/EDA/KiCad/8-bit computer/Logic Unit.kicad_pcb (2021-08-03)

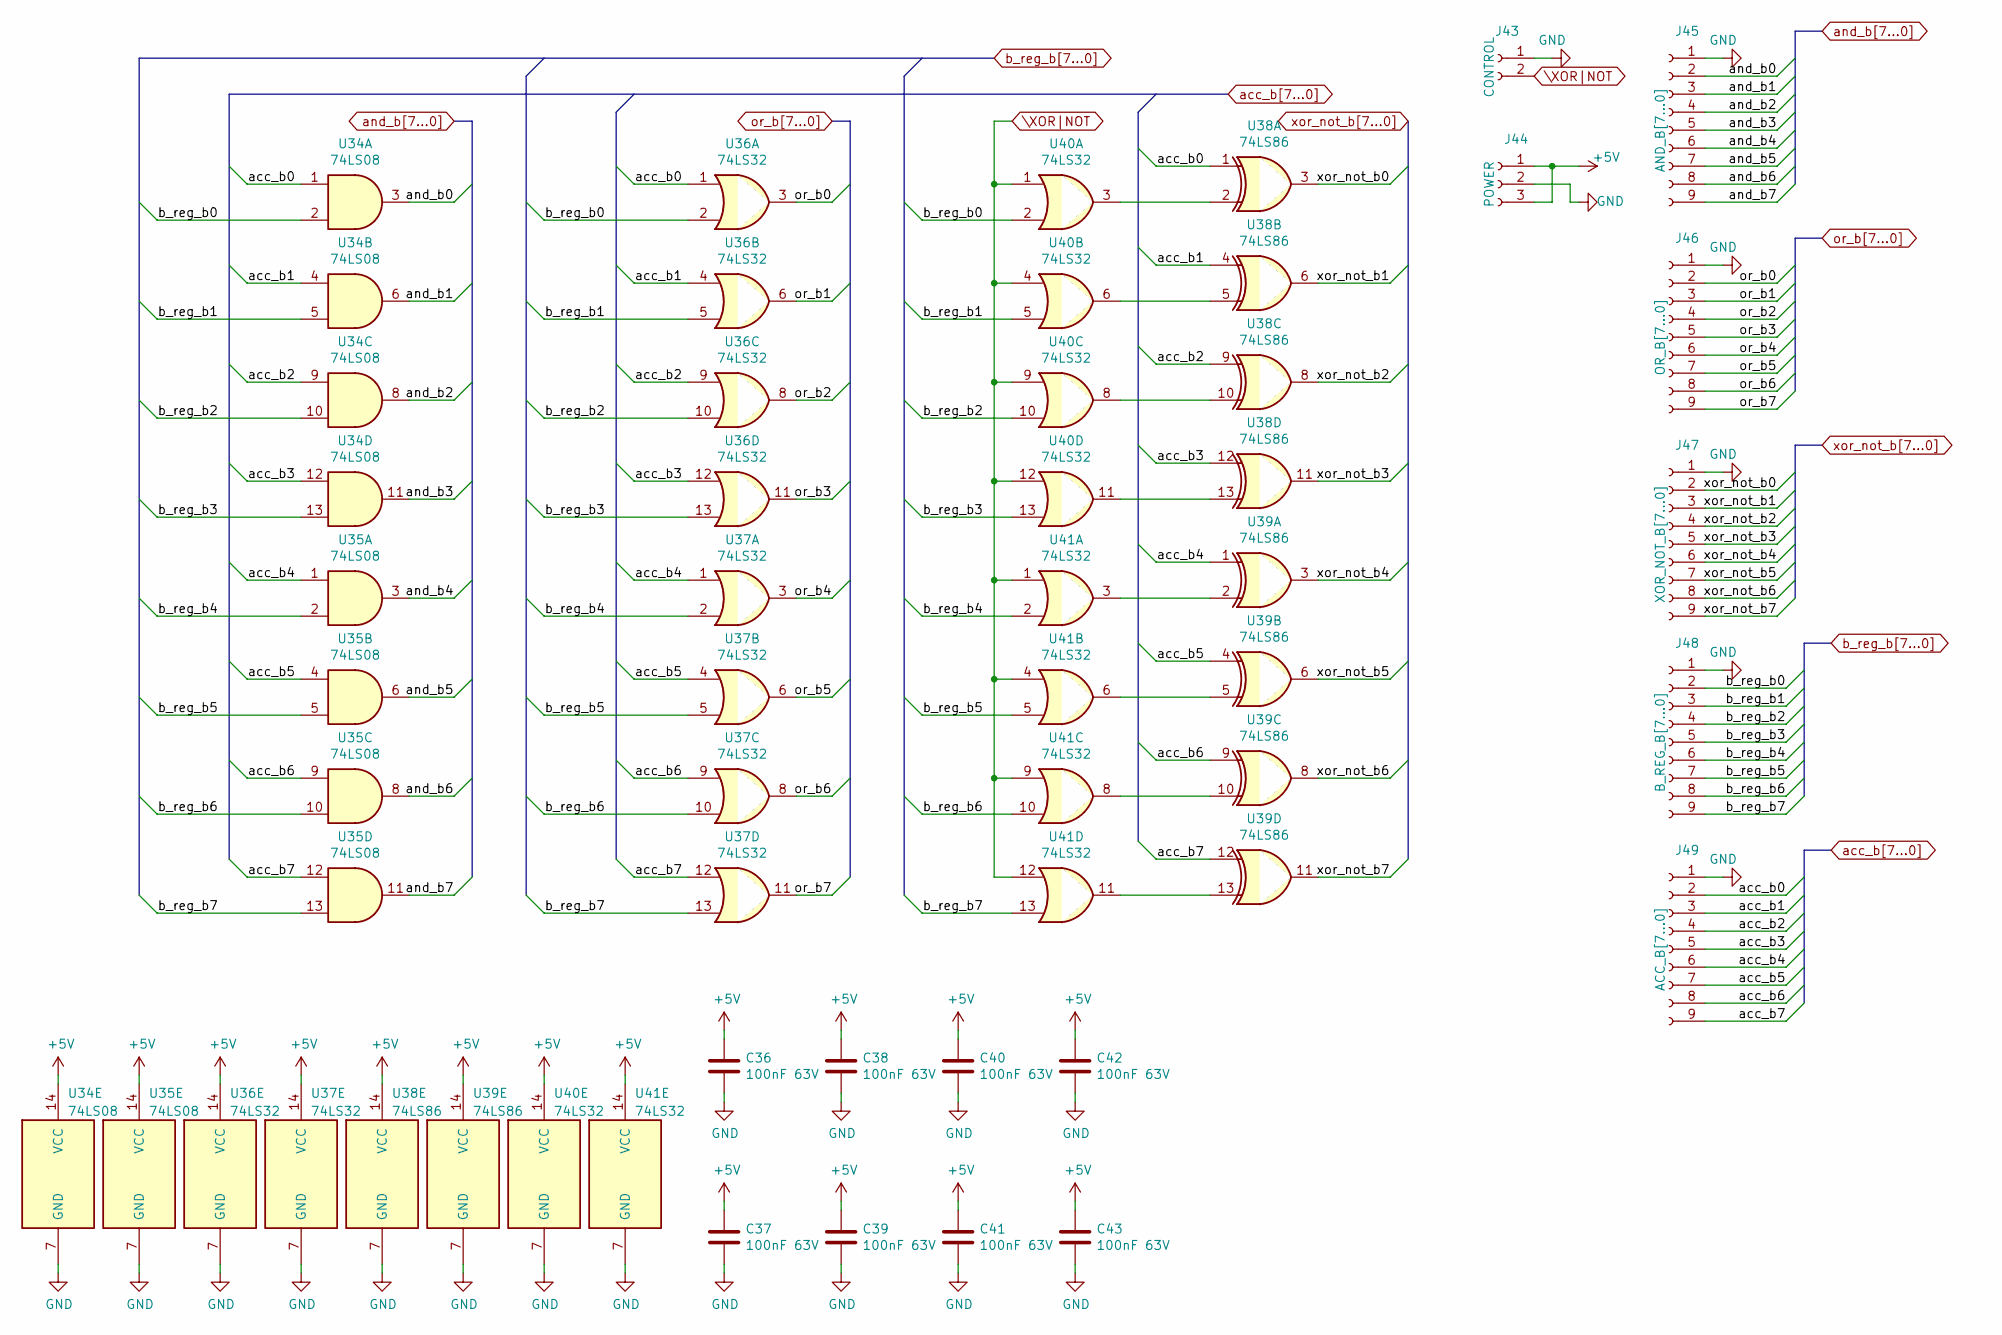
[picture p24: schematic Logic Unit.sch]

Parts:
C36, C37, C38, C39, C40, C41, C42, C43: 100nF 63V; C_Rect_L7.0mm_W2.5mm_P5.00mm
J43: CONTROL; PinSocket_1x02_P2.00mm_Vertical
J44: POWER; PinSocket_1x03_P2.00mm_Vertical
J45: AND_B[7...0]; PinSocket_1x09_P2.00mm_Vertical
J46: OR_B[7...0]; PinSocket_1x09_P2.00mm_Vertical
J47: XOR_NOT_B[7...0]; PinSocket_1x09_P2.00mm_Vertical
J48: B_REG_B[7...0]; PinSocket_1x09_P2.00mm_Vertical
J49: ACC_B[7...0]; PinSocket_1x09_P2.00mm_Vertical
U34, U35: 74LS08; DIP-14_W7.62mm_LongPads
U36, U37, U40, U41: 74LS32; DIP-14_W7.62mm_LongPads
U38, U39: 74LS86; DIP-14_W7.62mm_LongPads

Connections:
+5V: C36.1, C37.1, C38.1, C39.1, C40.1, C41.1, C42.1, C43.1, J44.1, J44.3, U34.14 (VCC), U35.14 (VCC), U36.14 (VCC), U37.14 (VCC), U38.14 (VCC), U39.14 (VCC), U40.14 (VCC), U41.14 (VCC)
GND: C36.2, C37.2, C38.2, C39.2, C40.2, C41.2, C42.2, C43.2, J43.1, J44.2, J45.1, J46.1, J47.1, J48.1, J49.1, U34.7 (GND), U35.7 (GND), U36.7 (GND), U37.7 (GND), U38.7 (GND), U39.7 (GND), U40.7 (GND), U41.7 (GND)
unnamed: U38.2, U40.3
unnamed: U38.5, U40.6
unnamed: U38.10, U40.8
unnamed: U38.13, U40.11
unnamed: U39.2, U41.3
unnamed: U39.5, U41.6
unnamed: U39.10, U41.8
unnamed: U39.13, U41.11
\XOR|NOT: J43.2, U40.1, U40.4, U40.9, U40.12, U41.1, U41.4, U41.9, U41.12
acc_b0: J49.2, U34.1, U36.1, U38.1
acc_b1: J49.3, U34.4, U36.4, U38.4
acc_b2: J49.4, U34.9, U36.9, U38.9
acc_b3: J49.5, U34.12, U36.12, U38.12
acc_b4: J49.6, U35.1, U37.1, U39.1
acc_b5: J49.7, U35.4, U37.4, U39.4
acc_b6: J49.8, U35.9, U37.9, U39.9
acc_b7: J49.9, U35.12, U37.12, U39.12
and_b0: J45.2, U34.3
and_b1: J45.3, U34.6
and_b2: J45.4, U34.8
and_b3: J45.5, U34.11
and_b4: J45.6, U35.3
and_b5: J45.7, U35.6
and_b6: J45.8, U35.8
and_b7: J45.9, U35.11
b_reg_b0: J48.2, U34.2, U36.2, U40.2
b_reg_b1: J48.3, U34.5, U36.5, U40.5
b_reg_b2: J48.4, U34.10, U36.10, U40.10
b_reg_b3: J48.5, U34.13, U36.13, U40.13
b_reg_b4: J48.6, U35.2, U37.2, U41.2
b_reg_b5: J48.7, U35.5, U37.5, U41.5
b_reg_b6: J48.8, U35.10, U37.10, U41.10
b_reg_b7: J48.9, U35.13, U37.13, U41.13
or_b0: J46.2, U36.3
or_b1: J46.3, U36.6
or_b2: J46.4, U36.8
or_b3: J46.5, U36.11
or_b4: J46.6, U37.3
or_b5: J46.7, U37.6
or_b6: J46.8, U37.8
or_b7: J46.9, U37.11
xor_not_b0: J47.2, U38.3
xor_not_b1: J47.3, U38.6
xor_not_b2: J47.4, U38.8
xor_not_b3: J47.5, U38.11
xor_not_b4: J47.6, U39.3
xor_not_b5: J47.7, U39.6
xor_not_b6: J47.8, U39.8
xor_not_b7: J47.9, U39.11

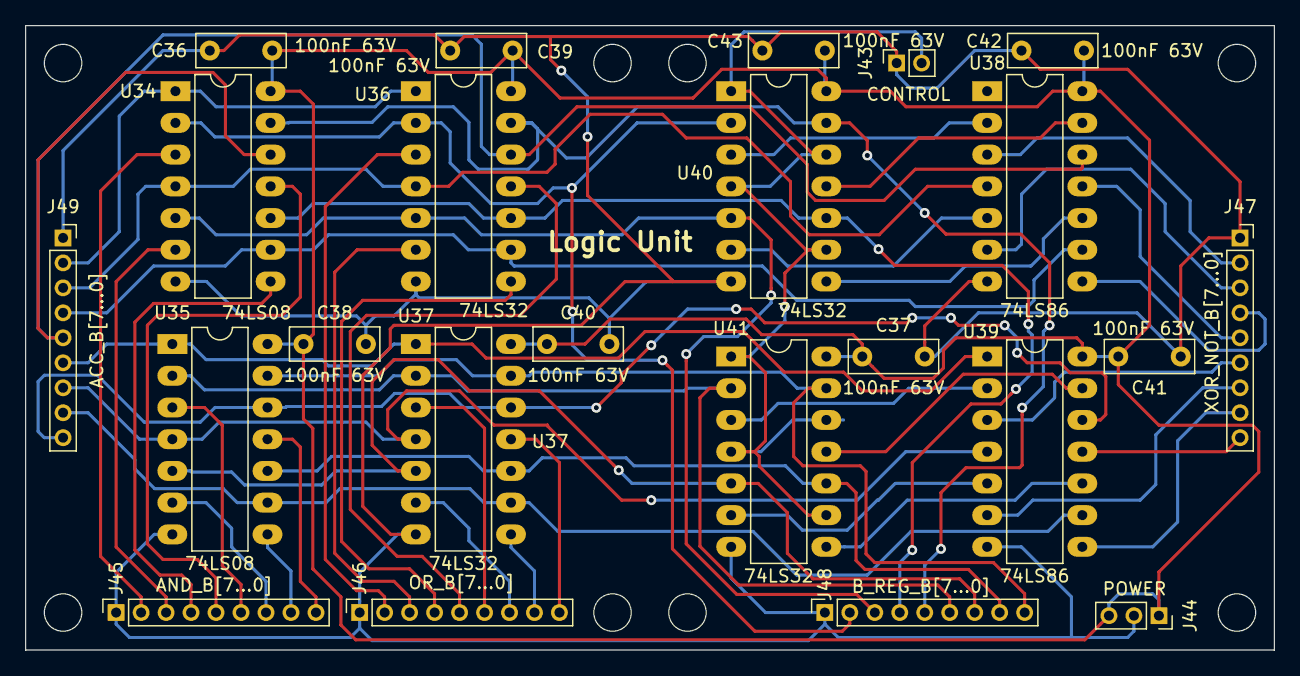
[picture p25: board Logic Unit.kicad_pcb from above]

Board: 2 copper layers, 100.0 x 50.0 mm, 23 parts (0 on the bottom side), 51 nets.

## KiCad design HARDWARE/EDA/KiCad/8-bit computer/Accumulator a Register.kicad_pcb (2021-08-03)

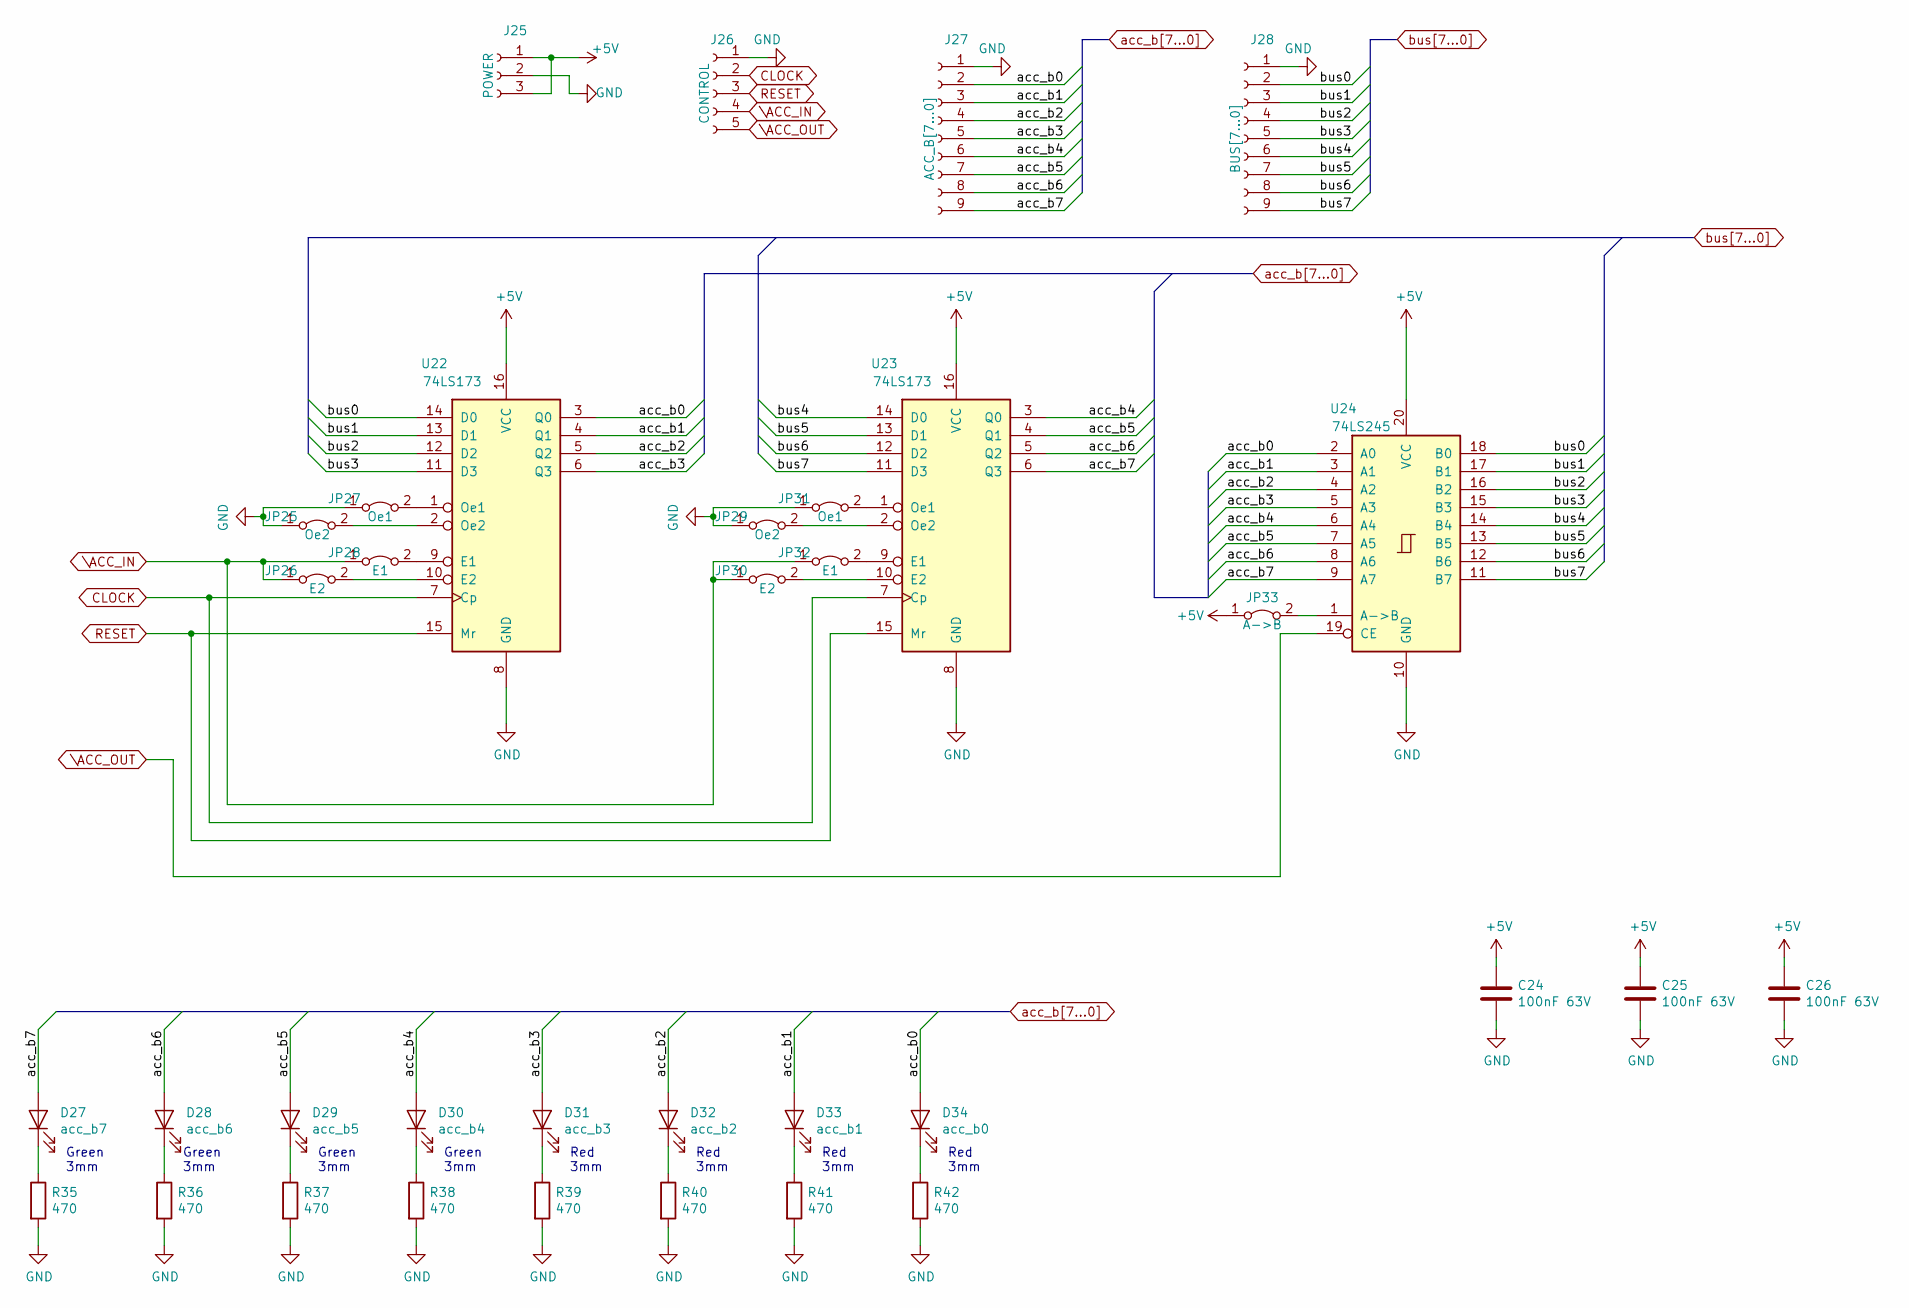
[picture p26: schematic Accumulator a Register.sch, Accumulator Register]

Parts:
C24, C25, C26: 100nF 63V; C_Rect_L7.0mm_W2.5mm_P5.00mm
D27: acc_b7; LED_D3.0mm
D28: acc_b6; LED_D3.0mm
D29: acc_b5; LED_D3.0mm
D30: acc_b4; LED_D3.0mm
D31: acc_b3; LED_D3.0mm
D32: acc_b2; LED_D3.0mm
D33: acc_b1; LED_D3.0mm
D34: acc_b0; LED_D3.0mm
J25: POWER; PinSocket_1x03_P2.00mm_Vertical
J26: CONTROL; PinSocket_1x05_P2.00mm_Vertical
J27: ACC_B[7...0]; PinSocket_1x09_P2.00mm_Vertical
J28: BUS[7...0]; PinSocket_1x09_P2.00mm_Vertical
JP25, JP29: Oe2; TestPoint_2Pads_Pitch2.54mm_Drill0.8mm
JP26, JP30: E2; TestPoint_2Pads_Pitch2.54mm_Drill0.8mm
JP27, JP31: Oe1; TestPoint_2Pads_Pitch2.54mm_Drill0.8mm
JP28, JP32: E1; TestPoint_2Pads_Pitch2.54mm_Drill0.8mm
JP33: A->B; TestPoint_2Pads_Pitch2.54mm_Drill0.8mm
R35, R36, R37, R38, R39, R40, R41, R42: 470; R_Axial_DIN0207_L6.3mm_D2.5mm_P7.62mm_Horizontal
U22, U23: 74LS173; DIP-16_W7.62mm_LongPads
U24: 74LS245; DIP-20_W7.62mm_LongPads

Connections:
+5V: C24.1, C25.1, C26.1, J25.1, J25.3, JP33.1 (A), U22.16 (VCC), U23.16 (VCC), U24.20 (VCC)
CLOCK: J26.2, U22.7 (Cp), U23.7 (Cp)
GND: C24.2, C25.2, C26.2, J25.2, J26.1, J27.1, J28.1, JP25.1 (A), JP27.1 (A), JP29.1 (A), JP31.1 (A), R35.2, R36.2, R37.2, R38.2, R39.2, R40.2, R41.2, R42.2, U22.8 (GND), U23.8 (GND), U24.10 (GND)
unnamed: D27.1 (K), R35.1
unnamed: D28.1 (K), R36.1
unnamed: D29.1 (K), R37.1
unnamed: D30.1 (K), R38.1
unnamed: D31.1 (K), R39.1
unnamed: D32.1 (K), R40.1
unnamed: D33.1 (K), R41.1
unnamed: D34.1 (K), R42.1
unnamed: JP25.2 (B), U22.2 (Oe2)
unnamed: JP26.2 (B), U22.10 (E2)
unnamed: JP27.2 (B), U22.1 (Oe1)
unnamed: JP28.2 (B), U22.9 (E1)
unnamed: JP29.2 (B), U23.2 (Oe2)
unnamed: JP30.2 (B), U23.10 (E2)
unnamed: JP31.2 (B), U23.1 (Oe1)
unnamed: JP32.2 (B), U23.9 (E1)
unnamed: JP33.2 (B), U24.1 (A->B)
RESET: J26.3, U22.15 (Mr), U23.15 (Mr)
\ACC_IN: J26.4, JP26.1 (A), JP28.1 (A), JP30.1 (A), JP32.1 (A)
\ACC_OUT: J26.5, U24.19 (CE)
acc_b0: D34.2 (A), J27.2, U22.3 (Q0), U24.2 (A0)
acc_b1: D33.2 (A), J27.3, U22.4 (Q1), U24.3 (A1)
acc_b2: D32.2 (A), J27.4, U22.5 (Q2), U24.4 (A2)
acc_b3: D31.2 (A), J27.5, U22.6 (Q3), U24.5 (A3)
acc_b4: D30.2 (A), J27.6, U23.3 (Q0), U24.6 (A4)
acc_b5: D29.2 (A), J27.7, U23.4 (Q1), U24.7 (A5)
acc_b6: D28.2 (A), J27.8, U23.5 (Q2), U24.8 (A6)
acc_b7: D27.2 (A), J27.9, U23.6 (Q3), U24.9 (A7)
bus0: J28.2, U22.14 (D0), U24.18 (B0)
bus1: J28.3, U22.13 (D1), U24.17 (B1)
bus2: J28.4, U22.12 (D2), U24.16 (B2)
bus3: J28.5, U22.11 (D3), U24.15 (B3)
bus4: J28.6, U23.14 (D0), U24.14 (B4)
bus5: J28.7, U23.13 (D1), U24.13 (B5)
bus6: J28.8, U23.12 (D2), U24.12 (B6)
bus7: J28.9, U23.11 (D3), U24.11 (B7)

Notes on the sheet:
Green 3mm
Red 3mm

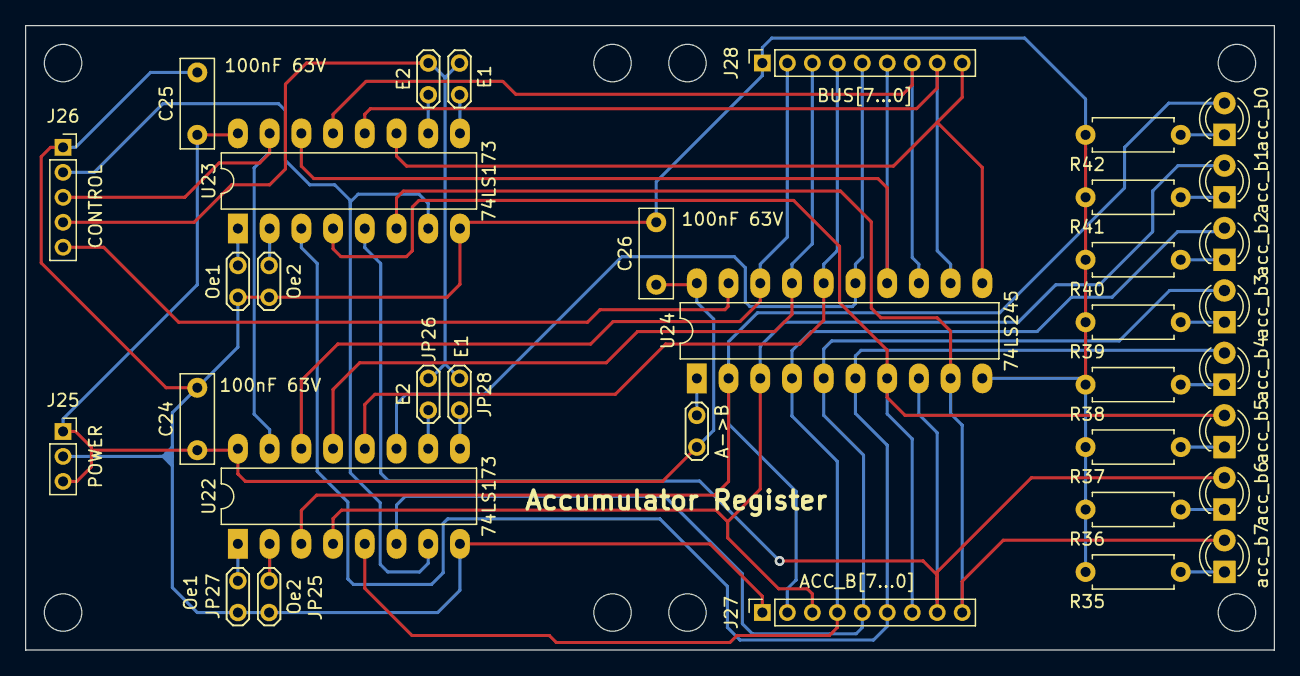
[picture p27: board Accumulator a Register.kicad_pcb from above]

Board: 2 copper layers, 100.0 x 50.0 mm, 35 parts (0 on the bottom side), 39 nets.

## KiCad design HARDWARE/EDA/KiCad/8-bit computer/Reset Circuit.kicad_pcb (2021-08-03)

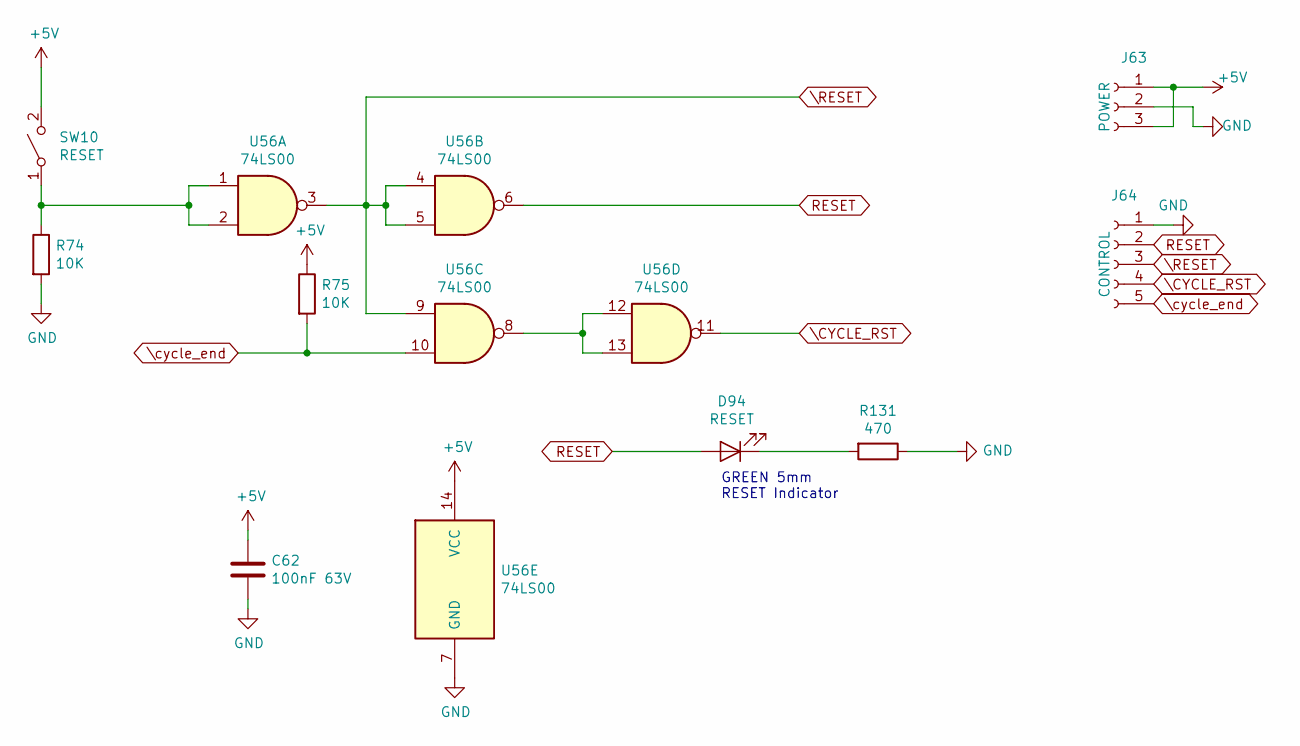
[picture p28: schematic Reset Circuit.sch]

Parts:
C62: 100nF 63V; C_Rect_L7.0mm_W2.5mm_P5.00mm
D94: RESET; LED_D3.0mm
J63: POWER; PinSocket_1x03_P2.00mm_Vertical
J64: CONTROL; PinSocket_1x05_P2.00mm_Vertical
R74, R75: 10K; R_Axial_DIN0207_L6.3mm_D2.5mm_P7.62mm_Horizontal
R131: 470; R_Axial_DIN0207_L6.3mm_D2.5mm_P7.62mm_Horizontal
SW10: RESET; SW_PUSH_6mm_H5mm
U56: 74LS00; DIP-14_W7.62mm_LongPads

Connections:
+5V: C62.1, J63.1, J63.3, R75.1, SW10.2 (B), U56.14 (VCC)
GND: C62.2, J63.2, J64.1, R74.2, R131.1, U56.7 (GND)
unnamed: D94.1 (K), R131.2
unnamed: R74.1, SW10.1 (A), U56.1, U56.2
unnamed: U56.8, U56.12, U56.13
RESET: D94.2 (A), J64.2, U56.6
\CYCLE_RST: J64.4, U56.11
\RESET: J64.3, U56.3, U56.4, U56.5, U56.9
\cycle_end: J64.5, R75.2, U56.10

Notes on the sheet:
GREEN 5mm RESET Indicator

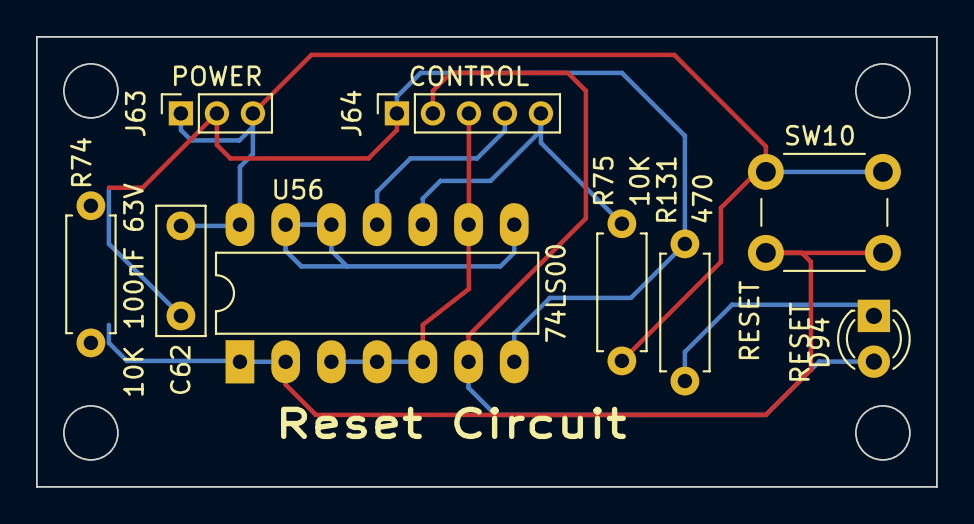
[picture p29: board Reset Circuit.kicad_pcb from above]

Board: 2 copper layers, 50.0 x 25.0 mm, 9 parts (0 on the bottom side), 9 nets.

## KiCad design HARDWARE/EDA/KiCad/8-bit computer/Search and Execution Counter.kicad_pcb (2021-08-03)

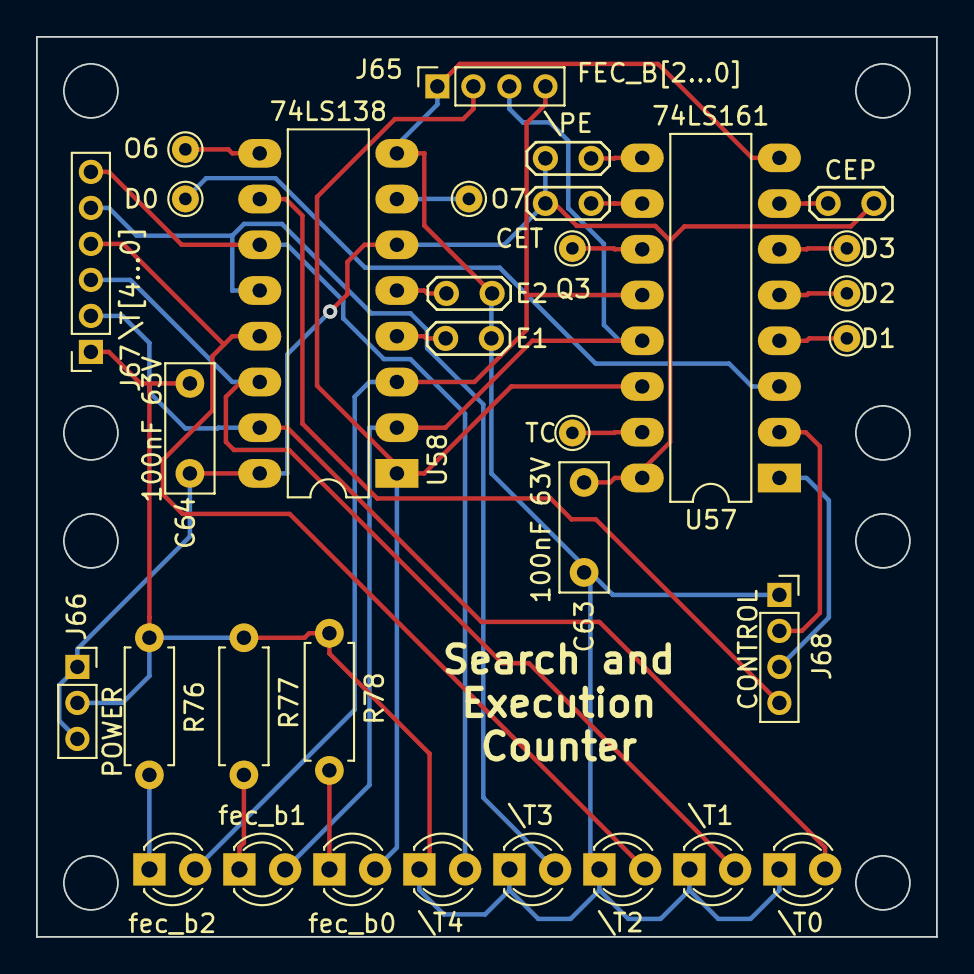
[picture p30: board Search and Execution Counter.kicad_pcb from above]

Board: 2 copper layers, 50.0 x 50.0 mm, 32 parts (0 on the bottom side), 29 nets.

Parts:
C63, C64: 100nF 63V; C_Rect_L7.0mm_W2.5mm_P5.00mm
D60: fec_b2; LED_D3.0mm_Clear
D61: fec_b1; LED_D3.0mm_Clear
D62: fec_b0; LED_D3.0mm_Clear
D63: \T4; LED_D3.0mm_Clear
D64: \T3; LED_D3.0mm_Clear
D65: \T2; LED_D3.0mm_Clear
D66: \T1; LED_D3.0mm_Clear
D67: \T0; LED_D3.0mm_Clear
J65: FEC_B[2...0]; PinSocket_1x04_P2.00mm_Vertical
J66: POWER; PinSocket_1x03_P2.00mm_Vertical
J67: \T[4...0]; PinSocket_1x06_P2.00mm_Vertical
J68: CONTROL; PinSocket_1x04_P2.00mm_Vertical
JP75: CEP; TestPoint_2Pads_Pitch2.54mm_Drill0.8mm
JP76: \PE; TestPoint_2Pads_Pitch2.54mm_Drill0.8mm
JP77: CET; TestPoint_2Pads_Pitch2.54mm_Drill0.8mm
JP78: E2; TestPoint_2Pads_Pitch2.54mm_Drill0.8mm
JP79: E1; TestPoint_2Pads_Pitch2.54mm_Drill0.8mm
R76, R77, R78: 330; R_Axial_DIN0207_L6.3mm_D2.5mm_P7.62mm_Horizontal
TP46: D0; TestPoint_THTPad_D1.5mm_Drill0.7mm
TP47: D1; TestPoint_THTPad_D1.5mm_Drill0.7mm
TP48: D2; TestPoint_THTPad_D1.5mm_Drill0.7mm
TP49: D3; TestPoint_THTPad_D1.5mm_Drill0.7mm
TP50: Q3; TestPoint_THTPad_D1.5mm_Drill0.7mm
TP51: TC; TestPoint_THTPad_D1.5mm_Drill0.7mm
TP52: O6; TestPoint_THTPad_D1.5mm_Drill0.7mm
TP53: O7; TestPoint_THTPad_D1.5mm_Drill0.7mm
U57: 74LS161; DIP-16_W7.62mm_LongPads
U58: 74LS138; DIP-16_W7.62mm_LongPads

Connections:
+5V: C63.1, C64.1, J66.1, J66.3, JP75.1, JP76.1, JP77.1, U57.16, U58.6, U58.16
/\T0: D67.2, J67.2, U58.15
/\T1: D66.2, J67.3, U58.14
/\T2: D65.2, J67.4, U58.13
/\T3: D64.2, J67.5, U58.12
/\T4: D63.2, J67.6, U58.11
GND: C63.2, C64.2, D63.1, D64.1, D65.1, D66.1, D67.1, J65.1, J66.2, J67.1, J68.1, JP78.1, JP79.1, R76.2, R77.2, R78.2, U57.8, U58.8
unnamed: D60.1, R76.1
unnamed: D61.1, R77.1
unnamed: D62.1, R78.1
unnamed: JP75.2, U57.7
unnamed: JP76.2, U57.9
unnamed: JP77.2, U57.10
unnamed: JP78.2, U58.5
unnamed: JP79.2, U58.4
unnamed: TP46.1, U57.3
unnamed: TP47.1, U57.4
unnamed: TP48.1, U57.5
unnamed: TP49.1, U57.6
unnamed: TP50.1, U57.11
unnamed: TP51.1, U57.15
unnamed: TP52.1, U58.9
unnamed: TP53.1, U58.7
\CLOCK: J68.2, U57.2
\CYCLE_RST: J68.3, U57.1
\cycle_end: J68.4, U58.10
fec_b0: D62.2, J65.2, U57.14, U58.1
fec_b1: D61.2, J65.3, U57.13, U58.2
fec_b2: D60.2, J65.4, U57.12, U58.3

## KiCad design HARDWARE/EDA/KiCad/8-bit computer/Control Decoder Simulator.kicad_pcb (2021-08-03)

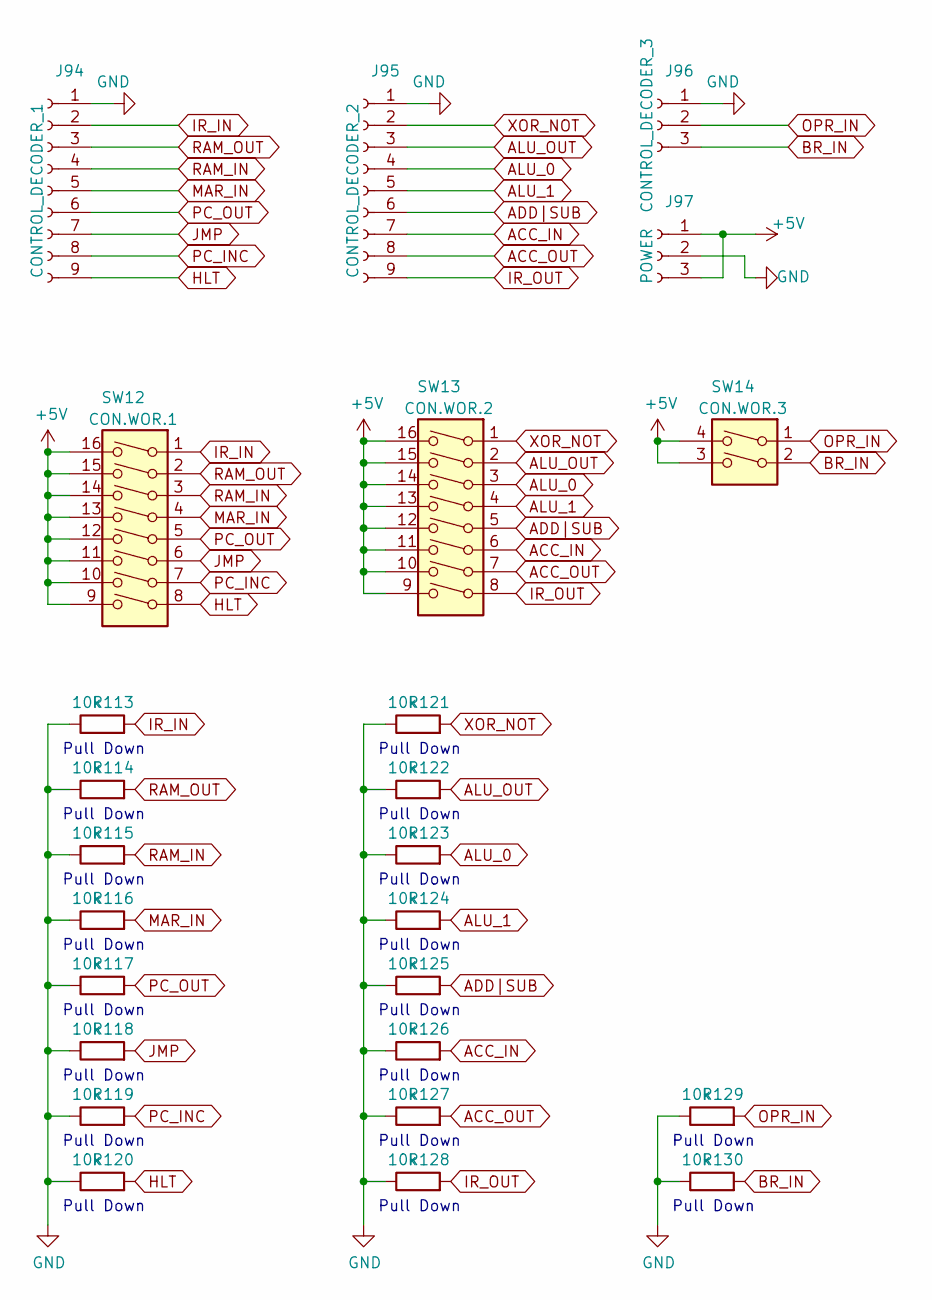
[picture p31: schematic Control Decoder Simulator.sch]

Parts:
J94: CONTROL_DECODER_1; PinSocket_1x09_P2.00mm_Vertical
J95: CONTROL_DECODER_2; PinSocket_1x09_P2.00mm_Vertical
J96: CONTROL_DECODER_3; PinSocket_1x03_P2.00mm_Vertical
J97: POWER; PinSocket_1x03_P2.00mm_Vertical
R113, R114, R115, R116, R117, R118, R119, R120, R121, R122, R123, R124, R125, R126, R127, R128, R129, R130: 10k; R_Axial_DIN0207_L6.3mm_D2.5mm_P7.62mm_Horizontal
SW12: CON.WOR.1; SW_DIP_SPSTx08_Slide_9.78x22.5mm_W7.62mm_P2.54mm
SW13: CON.WOR.2; SW_DIP_SPSTx08_Slide_9.78x22.5mm_W7.62mm_P2.54mm
SW14: CON.WOR.3; SW_DIP_SPSTx02_Slide_9.78x7.26mm_W7.62mm_P2.54mm

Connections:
+5V: J97.1, J97.3, SW12.9, SW12.10, SW12.11, SW12.12, SW12.13, SW12.14, SW12.15, SW12.16, SW13.9, SW13.10, SW13.11, SW13.12, SW13.13, SW13.14, SW13.15, SW13.16, SW14.3, SW14.4
ACC_IN: J95.7, R126.2, SW13.6
ACC_OUT: J95.8, R127.2, SW13.7
ADD|SUB: J95.6, R125.2, SW13.5
ALU_0: J95.4, R123.2, SW13.3
ALU_1: J95.5, R124.2, SW13.4
ALU_OUT: J95.3, R122.2, SW13.2
BR_IN: J96.3, R130.2, SW14.2
GND: J94.1, J95.1, J96.1, J97.2, R113.1, R114.1, R115.1, R116.1, R117.1, R118.1, R119.1, R120.1, R121.1, R122.1, R123.1, R124.1, R125.1, R126.1, R127.1, R128.1, R129.1, R130.1
HLT: J94.9, R120.2, SW12.8
IR_IN: J94.2, R113.2, SW12.1
IR_OUT: J95.9, R128.2, SW13.8
JMP: J94.7, R118.2, SW12.6
MAR_IN: J94.5, R116.2, SW12.4
OPR_IN: J96.2, R129.2, SW14.1
PC_INC: J94.8, R119.2, SW12.7
PC_OUT: J94.6, R117.2, SW12.5
RAM_IN: J94.4, R115.2, SW12.3
RAM_OUT: J94.3, R114.2, SW12.2
XOR_NOT: J95.2, R121.2, SW13.1

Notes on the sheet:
Pull Down


Board: 2 copper layers, 60.0 x 50.0 mm, 25 parts (0 on the bottom side), 20 nets.
